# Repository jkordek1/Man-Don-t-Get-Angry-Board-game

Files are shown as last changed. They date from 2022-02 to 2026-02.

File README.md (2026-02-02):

# Man, Don't Get Angry - Board game


[]()



## About


Mensch ärgere Dich nicht (English: Man, Don't Get Angry) is a German board game developed by Josef Friedrich Schmidt in 1907/1908.
The name derives from the fact that a peg is sent back to the "out" field when another peg lands on it, similar to the later game Sorry!.

More information about the game can be found at the [wiki page](https://en.wikipedia.org/wiki/Mensch_%C3%A4rgere_Dich_nicht).

## Project idea
Idea of the project is to create an electronic version of the game to help promoting STEM education (and to have some fun of course).

## Project status
- [x] Breadboard prototype
- [x] Schematic
- [x] PCBs
- [x] Enclosure design
- [x] 3D CAD assembly and renders
- [x] Assembly
- [ ] Programming

## Issues
- no active issues

## Main features
- Based on popular ATmega328p microcontroller used on Arduino boards
- WS2812B-V5 addressable LEDs with no external components needed
- WS2812-mini addressable LED used as battery level indicator
- Touchpads connected via PCF8575 I/O Expander used as controls
- Piezo buzzer for audio queues
- 3000mAh rechargable Li-Po battery
- USB-C connector for charging and programming the microcontroller

## 3D renders
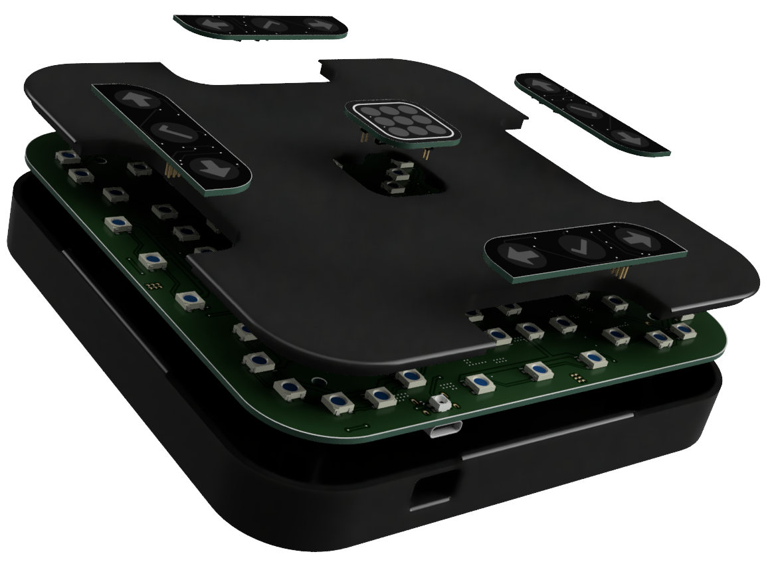
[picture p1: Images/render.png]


## Images
<p align="center">
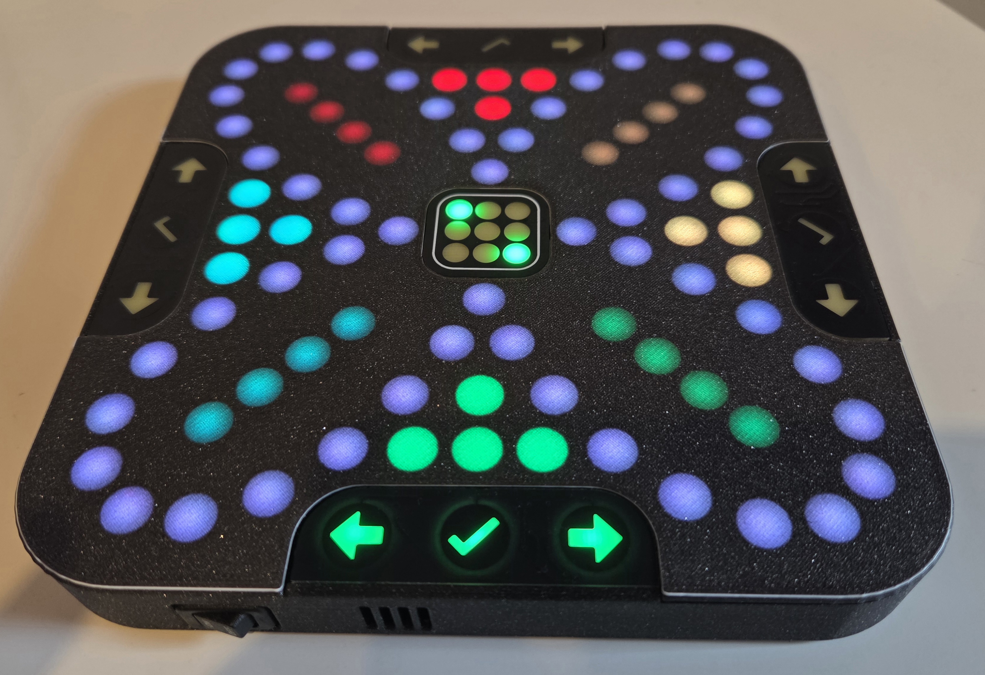
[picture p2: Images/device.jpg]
  
</p>

## PCBs
There are 3 different PCBs:

**BoardGame** - main 150x150mm PCB that contains LEDs and most of the electronic components (1 needed)

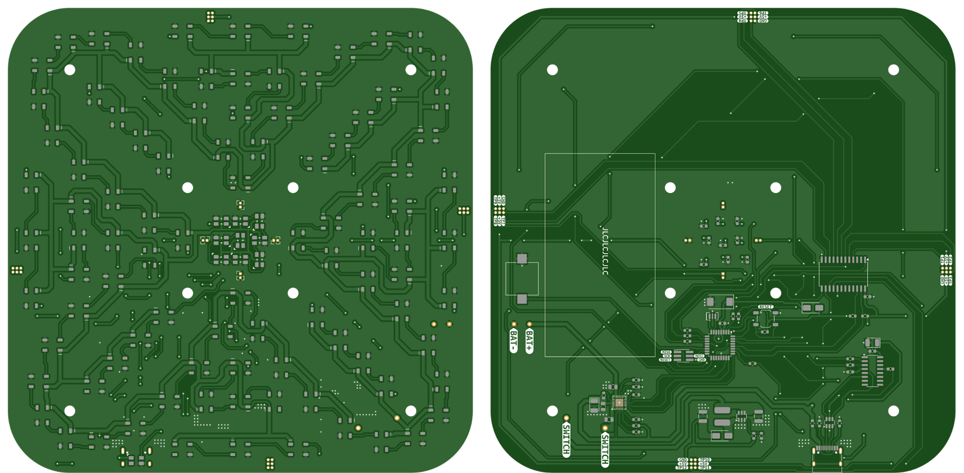
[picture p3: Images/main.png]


**Dice** - small PCB used as a touchpad (1 needed)

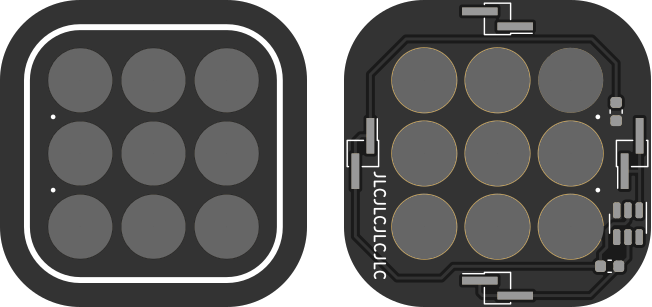
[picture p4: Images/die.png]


**Touchpad** - PCB with 3 touchpads used as controls for the game (4 needed)

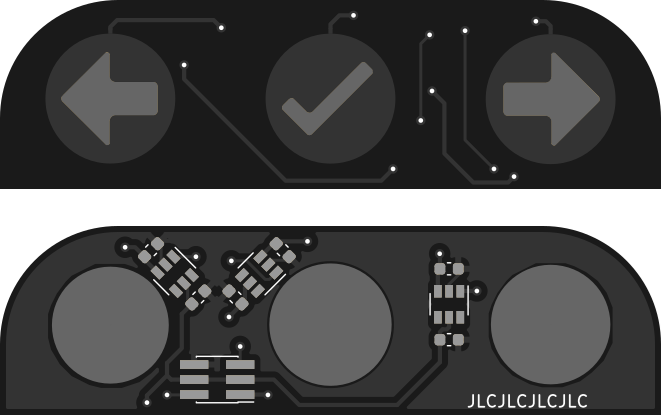
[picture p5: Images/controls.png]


## Enclosure
There are few 3D models files needed for enclosure:
1. Case - main part of the enclosure
2. FieldBoard - Upper part of the enclosure printed with black and white filaments

## Project folder structure
    .
    ├── ...
    ├── Images                  # Images of the project
    ├── Solidworks assembly     # Enclosure and PCB 3D model files
    ├── KiCad files             # Main folder
    │   ├── 3D models           # 3d models of components
    │   ├── BoardGame           # KiCAD project for main PCB
    │   ├── Dice                # KiCAD project for dice
    │   └── Touchpad            # KiCAD project for touchpad controls
    └── ...

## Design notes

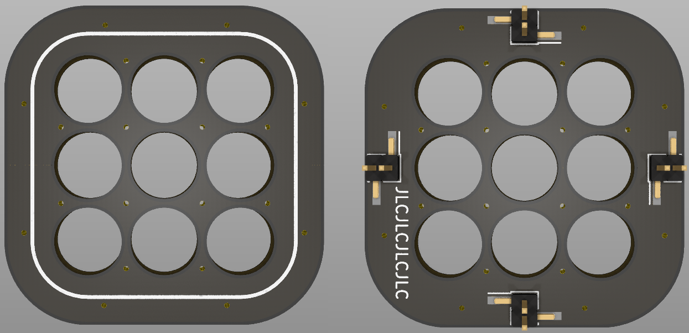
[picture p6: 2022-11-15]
Images/Dice-front and back.png

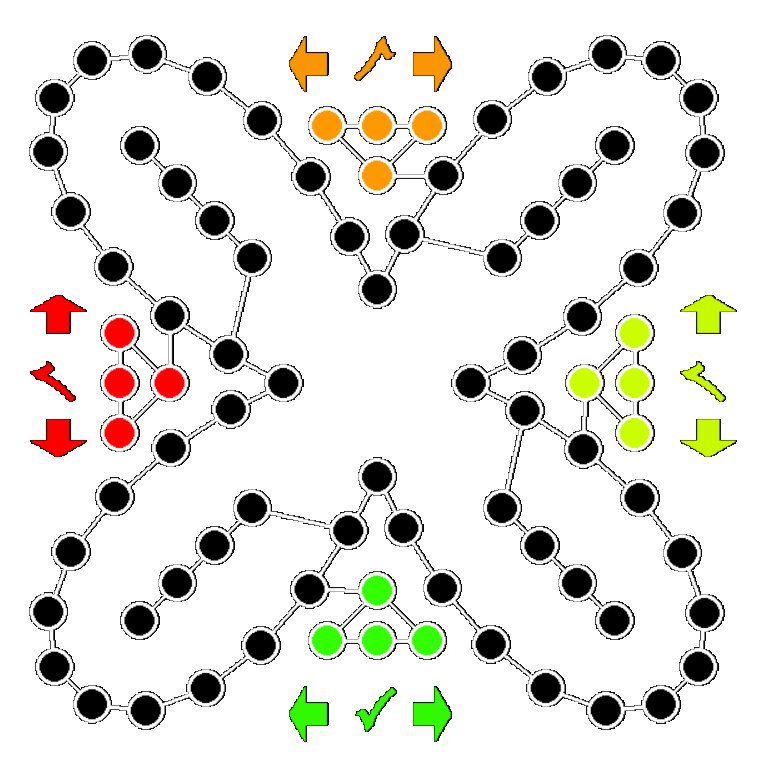
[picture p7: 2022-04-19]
Images/Positions_v3.png

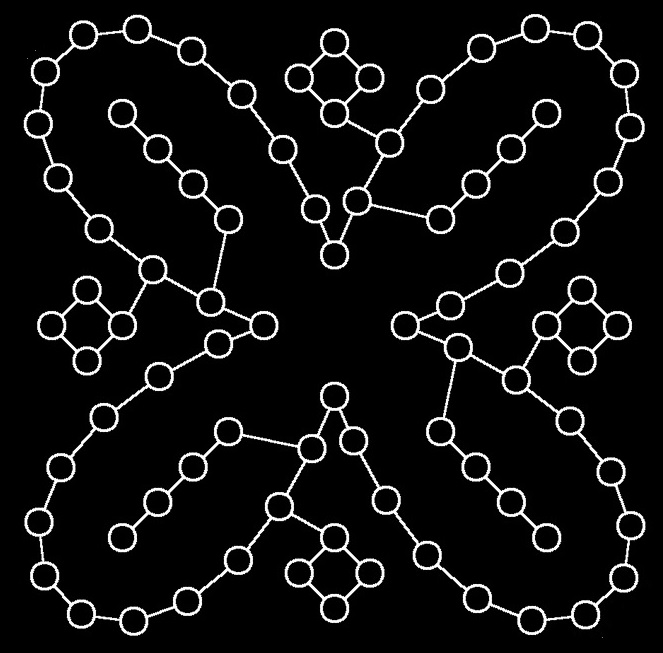
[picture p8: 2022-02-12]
Images/Positions_rotated.jpg

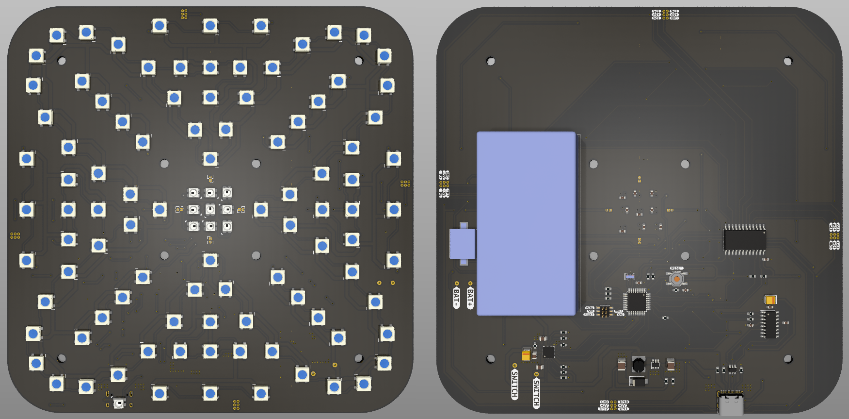
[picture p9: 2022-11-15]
Images/BoardGame-front and back.png

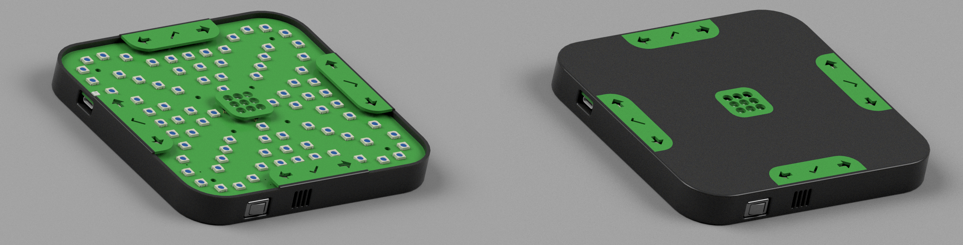
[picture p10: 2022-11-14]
Images/BoardGameV1.png

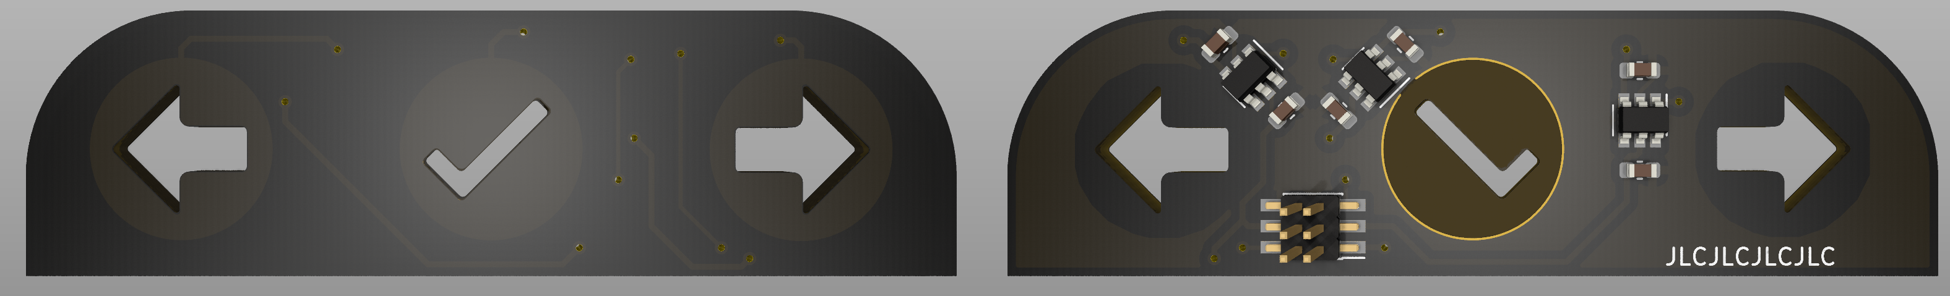
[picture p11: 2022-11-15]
Images/Touchpad-front and back.png

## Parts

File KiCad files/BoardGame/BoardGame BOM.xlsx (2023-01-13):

Component | Part | Value | Footprint | Quantity Per PCB | Datasheet
1 | C_Small | 100n | C_0603_1608Metric | 30 | ~
2 | C_Small | 1u | C_0603_1608Metric | 1 | ~
3 | C_Polarized_Small | 10u | CP_EIA-3528-21_Kemet-B | 1 | ~
4 | C_Small | 10u | C_0805_2012Metric | 3 | ~
5 | C_Polarized_Small | 1500uF | CP_EIA-7343-31_Kemet-D | 1 | ~
6 | C_Small | 22u / 16V | C_1210_3225Metric | 2 | ~
7 | C_Polarized_Small | 4u7/25V | CP_EIA-3528-21_Kemet-B | 1 | ~
8 | D_Schottky_Small | SS12 | D_SMA | 2 | ~
9 | WS2812B-V5 | WS2812B-V5 | WS2812B-V5 | 96 | https://cdn-shop.adafruit.com/datasheets/WS2812B.pdf
10 | WS2812B-mini | WS2812B-mini | WS2812B-mini | 10
11 | FerriteBead | 100 @ 100MHz | R_0603_1608Metric | 1 | ~
12 | Conn_02x03_Odd_Even | USBasp | PinHeader_2x03_P1.27mm_Vertical_SMD | 1 | ~
13 | L_Small | 4R7 | Inductor_4mm(5x5mm pads) | 1 | ~
14 | Speaker | Buzzer | KLJ-1102 | 1 | ~
15 | R_Small | 470R | R_0603_1608Metric | 6 | ~
16 | R_Small | 1k | R_0603_1608Metric | 2 | ~
17 | R_Small | 2k | R_0603_1608Metric | 1 | ~
18 | R_Small | 4k7 | R_0603_1608Metric | 2 | ~
19 | R_Small | 5k1 | R_0603_1608Metric | 2 | ~
20 | R_Small | 10k | R_0603_1608Metric | 6 | ~
21 | R_Small | 13k3 | R_0603_1608Metric | 1 | ~
22 | R_Small | 100k | R_0603_1608Metric | 2 | ~
23 | SW_Push | SW_Push | SW_SPST_TL3342 | 1 | ~
24 | ATmega328P-A | ATmega328P-A | TQFP-32_7x7mm_P0.8mm | 1 | http://ww1.microchip.com/downloads/en/DeviceDoc/ATmega328_P%20AVR%20MCU%20with%20picoPower%20Technology%20Data%20Sheet%2040001984A.pdf
25 | CH340C | CH340C | SOIC-16_3.9x9.9mm_P1.27mm | 1 | https://datasheet.lcsc.com/szlcsc/Jiangsu-Qin-Heng-CH340C_C84681.pdf
26 | MCP73871-2CC | MCP73871-2CC | QFN-20-1EP_4x4mm_P0.5mm_EP2.5x2.5mm | 1 | http://www.mouser.com/ds/2/268/22090a-52174.pdf
27 | MT3608 | MT3608 | SOT-23-6 | 1 | https://www.olimex.com/Products/Breadboarding/BB-PWR-3608/resources/MT3608.pdf
28 | PCF8575 | PCF8575 | SOIC-24W_7.5x15.4mm_P1.27mm | 1
29 | USBLC6-2SC6 | USBLC6-2SC6 | SOT-23-6 | 1 | https://www.st.com/resource/en/datasheet/usblc6-2.pdf
30 | Resonator_Small | 16MHz | CSTCE16M0V53-R0 | 1 | ~
31 | C_Small | 50 pF | C_0603_1608Metric | 15
32 | Conn_02x03_Counter_Clockwise | Conn_02x03_Counter_Clockwise | PinHeader_2x03_P1.27mm_Vertical_SMD | 4
33 | TTP223-BA6 | TTP223-BA6 | SOT-23-6 | 15
34 | Conn_01x02_Male | Conn_01x02_Male | PinHeader_1x02_P1.27mm_Vertical_SMD_Pin1Left | 4
35 | Conn_01x02_Male | Conn_01x02_Male | PinHeader_1x02_P1.27mm_Vertical_SMD_Pin1Left | 4

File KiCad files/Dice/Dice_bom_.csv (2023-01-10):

Component | Description | Part | References | Value | Footprint | Quantity Per PCB | Datasheet
1 | Unpolarized capacitor, small symbol | C_Small | C1 | 100n | C_0603_1608Metric | 1 | ~
2 | Unpolarized capacitor, small symbol | C_Small | C2 | 0-50 pF | C_0603_1608Metric | 1 | ~
3 | Generic connector, single row, 01x02, script generated (kicad-library-utils/schlib/autogen/connector/) | Conn_01x02_Male | J1 J2 J3 J4 | Conn_01x02_Male | PinHeader_1x02_P1.27mm_Vertical_SMD_Pin1Left | 4 | ~
4 |  | TTP223-BA6 | U1 | TTP223-BA6 | SOT-23-6 | 1
Component Groups: | 4
Component Count: | 7
Fitted Components: | 7
Number of PCBs: | 1
Total components: | 7
Schematic Version:
Schematic Date:
PCB Variant: | default
BoM Date: | 10.1.2023. 13:12:25
Schematic Source: | Dice.kicad_sch
KiCad Version: | Eeschema (6.0.10)

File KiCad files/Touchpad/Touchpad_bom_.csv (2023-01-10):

Component | Description | Part | References | Value | Footprint | Quantity Per PCB | Datasheet
1 | Unpolarized capacitor, small symbol | C_Small | C2 C4 C6 | 100n | C_0603_1608Metric | 3 | ~
2 | Unpolarized capacitor, small symbol | C_Small | C1 C3 C5 | 0-50 pF | C_0603_1608Metric | 3 | ~
3 | Generic connector, double row, 02x03, counter clockwise pin numbering scheme (similar to DIP packge numbering), script generated (kicad-library-utils/schlib/autogen/connector/) | Conn_02x03_Counter_Clockwise | J1 | Conn_02x03_Counter_Clockwise | PinHeader_2x03_P1.27mm_Vertical_SMD | 1 | ~
4 |  | TTP223-BA6 | U1 U2 U3 | TTP223-BA6 | SOT-23-6 | 3
Component Groups: | 4
Component Count: | 10
Fitted Components: | 10
Number of PCBs: | 1
Total components: | 10
Schematic Version:
Schematic Date:
PCB Variant: | default
BoM Date: | 10.1.2023. 13:06:24
Schematic Source: | Touchpad.kicad_sch
KiCad Version: | Eeschema (6.0.10)

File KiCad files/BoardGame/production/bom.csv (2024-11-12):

Designator | Footprint | Quantity | Value | LCSC Part #
BT301 | battery_103565_3000mah | 1 | Battery_Cell | -
C1001, C1002, C1003, C1004, C1005, C1006, C1007, C1008, C1009, C201, C202, C204, C401, C501 | 0603 | 14 | 100n | C113803
C203 | CP_EIA-3528-21_Kemet-B | 1 | 10u | C2798040
C301 | CP_EIA-3528-21_Kemet-B | 1 | 4u7/25V | C2798040
C302, C303, C304 | 0805 | 3 | 10u | C237493
C502 | CP_EIA-7343-31_Kemet-D | 1 | 1500uF
C601, C602 | 1210 | 2 | 22u / 16V | C337451
D1001, D1002, D1003, D1004, D1005, D1006, D1007, D1008, D1009, D1010, D1011, D1012, D1013, D1014, D1015, D1016, D1017, D1018, D1019, D1020, D1021, D1022, D1023, D1024, D1025, D1026, D1027, D1028, D1029, D1030, D1031, D1032, D1033, D1034, D1035, D1036, D1037, D1038, D1039, D1040, D1041, D1042, D1043, D1044, D1045, D1046, D1047, D1048, D1049, D1050, D1051, D1052, D1053, D1054, D1055, D1056, D1057, D1058, D1059, D1060, D1061, D1062, D1063, D1064, D1065, D1066, D1067, D1068, D1069, D1070, D1071, D1072, D1073, D1074, D1075, D1076, D1077, D1078, D1079, D1080, D1081, D1082, D1083, D1084, D1085, D1086, D1087, D1088, D1089, D1090, D1091, D1092, D1093, D1094, D1095, D1096 | LED_WS2812B_edited | 96 | WS2812B | -
D1097, D1098, D1099, D1100, D1101, D1102, D1103, D1104, D1105 | WS2812-mini | 9 | WS2812B | C527089
D1106 | WS2812-mini | 1 | WS2812B | -
D501, D601 | D_SMA | 2 | SS12 | C2985002
FB201 | 0603 | 1 | 100 @ 100MHz | C107332
H1001, H1002, H1003, H1004, H1005, H1006, H1007, H1008 | MountingHole_3.2mm_M3 | 8 | MountingHole
J201 | USB_C_Receptacle_HRO_TYPE-C-31-M-12 | 1 | USB_C_Receptacle_USB2.0 | -
J301, J302 | PinHeader_1x01 | 2 | Conn_01x01 | -
J401, J402, J403, J404 | 2x03_P1.27mm_conn | 4 | Conn_02x03_Odd_Even | -
J405, J406, J407, J408 | PinHeader_1x02_P1.27mm_Vertical | 4 | Conn_01x02_Female
J501 | PinHeader_2x03_P1.27mm_Vertical_SMD | 1 | USBasp | -
L601 | Inductor_4mm(5x5mm pads) | 1 | 4R7
LS501 | KLJ-1102 | 1 | Buzzer
R1001, R1002, R1003, R1004, R1005, R1006 | 0603 | 6 | 470R
R201, R204 | 0603 | 2 | 1k
R202, R203 | 0603 | 2 | 5k1 | C3017721
R301, R303, R307, R308, R310, R501 | 0603 | 6 | 10k
R302 | 0603 | 1 | 2k | C25590
R305, R601 | 0603 | 2 | 100k
R401, R402 | 0603 | 2 | 4k7 | C114662
R602 | 0603 | 1 | 13k3 | C185373
SW501 | SW_SPST_TL3342 | 1 | SW_Push | C2886894
U201 | SOT-23-6 | 1 | USBLC6-2SC6 | C3029034
U202 | SOIC-16_3.9x9.9mm_P1.27mm | 1 | CH340C
U301 | QFN-20-1EP_4x4mm_P0.5mm_EP2.5x2.5mm | 1 | MCP73871-2CC
U401 | SOIC-24W_7.5x15.4mm_P1.27mm | 1 | PCF8575
U501 | TQFP-32_7x7mm_P0.8mm | 1 | ATmega328P-A
U601 | SOT-23-6 | 1 | MT3608 | C2932326
Y501 | CSTCE16M0V53-R0 | 1 | 16MHz | C32180

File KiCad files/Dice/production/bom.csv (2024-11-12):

Designator | Footprint | Quantity | Value | LCSC Part #
C1 | 0603 | 1 | 100n
C2 | 0603 | 1 | 0-50 pF
J1, J2, J3, J4 | PinHeader_1x02_P1.27mm_Vertical_SMD_Pin1Left | 4 | Conn_01x02_Male
U1 | SOT-23-6 | 1 | TTP223-BA6

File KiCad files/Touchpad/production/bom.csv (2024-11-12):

Designator | Footprint | Quantity | Value | LCSC Part #
C1, C3, C5 | 0603 | 3 | 0-50 pF
C2, C4, C6 | 0603 | 3 | 100n
J1 | PinHeader_2x03_P1.27mm_Vertical_SMD | 1 | Conn_02x03_Counter_Clockwise
TP1 | TP_11mm_kvacica | 1 | TestPoint
TP2 | TP_11mm_strelicaLijevo | 1 | TestPoint
TP3 | TP_11mm_strelicaDesno | 1 | TestPoint
U1, U2, U3 | SOT-23-6 | 3 | TTP223-BA6

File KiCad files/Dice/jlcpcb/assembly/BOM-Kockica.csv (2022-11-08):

Comment | Designator | Footprint | LCSC
Conn_01x02_Male | J1 | PinHeader_1x02_P1.27mm_Vertical_SMD_Pin1Left
Conn_01x02_Male | J4 | PinHeader_1x02_P1.27mm_Vertical_SMD_Pin1Left
Conn_01x02_Male | J3 | PinHeader_1x02_P1.27mm_Vertical_SMD_Pin1Left
Conn_01x02_Male | J2 | PinHeader_1x02_P1.27mm_Vertical_SMD_Pin1Left

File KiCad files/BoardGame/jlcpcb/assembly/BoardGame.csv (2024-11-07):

Id | Package | Quantity | Designation
1 | D_SMA | 2 | SS12
2 | LED_WS2812B_edited | 96 | WS2812B
3 | WS2812-mini | 10 | WS2812B
4 | MountingHole_3.2mm_M3 | 8 | MountingHole
5 | 2x03_P1.27mm_conn | 4 | Conn_02x03_Odd_Even
6 | PinHeader_1x01 | 2 | Conn_01x01
7 | PinHeader_1x02_P1.27mm_Vertical | 4 | Conn_01x02_Female
8 | C_0603_1608Metric | 14 | 100n
9 | R_0603_1608Metric | 6 | 10k
10 | C_0603_1608Metric | 1 | 1u
11 | R_0603_1608Metric | 2 | 1k
12 | R_0603_1608Metric | 2 | 4k7
13 | R_0603_1608Metric | 6 | 470R
14 | R_0603_1608Metric | 2 | 5k1
15 | KLJ-1102 | 1 | Buzzer
16 | TQFP-32_7x7mm_P0.8mm | 1 | ATmega328P-A
17 | R_0603_1608Metric | 1 | 13k3
18 | C_1210_3225Metric | 2 | 22u / 16V
19 | CP_EIA-3528-21_Kemet-B | 1 | 10u
20 | Inductor_4mm(5x5mm pads) | 1 | 4R7
21 | C_0805_2012Metric | 3 | 10u
22 | USB_C_Receptacle_HRO_TYPE-C-31-M-12 | 1 | USB_C_Receptacle_USB2.0
23 | R_0603_1608Metric | 1 | 100 @ 100MHz
24 | SOT-23-6 | 1 | MT3608
25 | CP_EIA-3528-21_Kemet-B | 1 | 4u7/25V
26 | SOIC-16_3.9x9.9mm_P1.27mm | 1 | CH340C
27 | SOT-23-6 | 1 | USBLC6-2SC6
28 | SW_SPST_TL3342 | 1 | SW_Push
29 | R_0603_1608Metric | 2 | 100k
30 | CP_EIA-7343-31_Kemet-D | 1 | 1500uF
31 | battery_103565_3000mah | 1 | Battery_Cell
32 | R_0603_1608Metric | 1 | 2k
33 | SOIC-24W_7.5x15.4mm_P1.27mm | 1 | PCF8575
34 | CSTCE16M0V53-R0 | 1 | 16MHz
35 | QFN-20-1EP_4x4mm_P0.5mm_EP2.5x2.5mm | 1 | MCP73871-2CC
36 | PinHeader_2x03_P1.27mm_Vertical_SMD | 1 | USBasp

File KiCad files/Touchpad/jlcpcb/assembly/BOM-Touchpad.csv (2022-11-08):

Comment | Designator | Footprint | LCSC
TestPoint | TP3 | TP_11mm_strelicaDesno
TestPoint | TP1 | TP_11mm_kvacica
TestPoint | TP2 | TP_11mm_strelicaLijevo
0-50 pF | C3 | C_0603_1608Metric
100n | C2 | C_0603_1608Metric
TTP223-BA6 | U3 | SOT-23-6
100n | C4 | C_0603_1608Metric
100n | C6 | C_0603_1608Metric
TTP223-BA6 | U2 | SOT-23-6
0-50 pF | C1 | C_0603_1608Metric
TTP223-BA6 | U1 | SOT-23-6
Conn_02x03_Counter_Clockwise | J1 | PinHeader_2x03_P1.27mm_Vertical_SMD
0-50 pF | C5 | C_0603_1608Metric

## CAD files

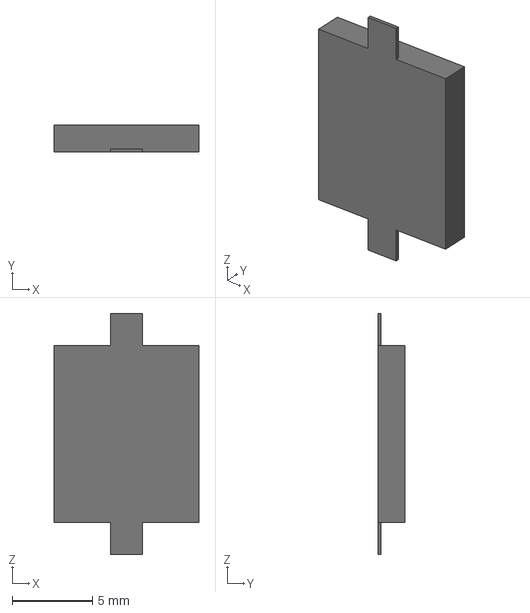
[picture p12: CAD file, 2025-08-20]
KiCad files/3D models/KLJ-1102.STEP
9.00 x 1.70 x 15.0 mm

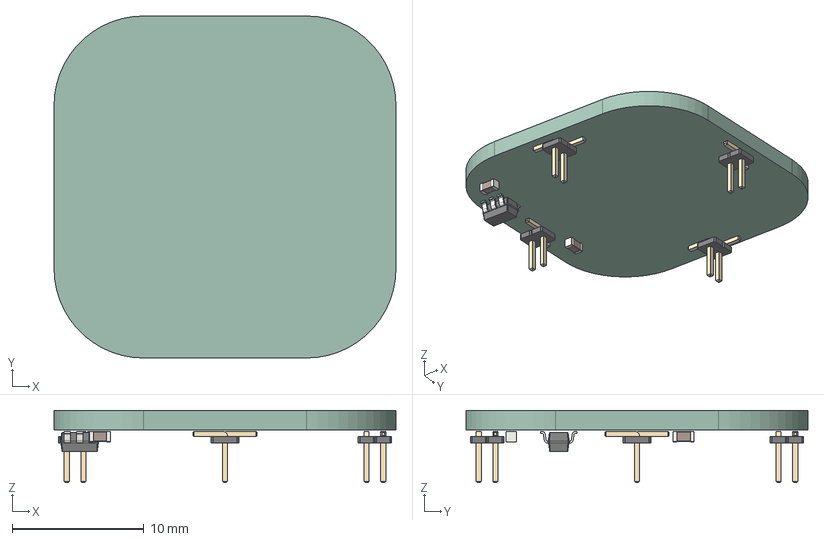
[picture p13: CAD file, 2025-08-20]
KiCad files/Dice/Kockica.step
26.0 x 26.0 x 5.50 mm
PinHeader_1x02_P1.27mm_Vertical_SMD_Pin1Left x 4
SOT-23-6
C_0603_1608Metric x 2
Dice_PCB

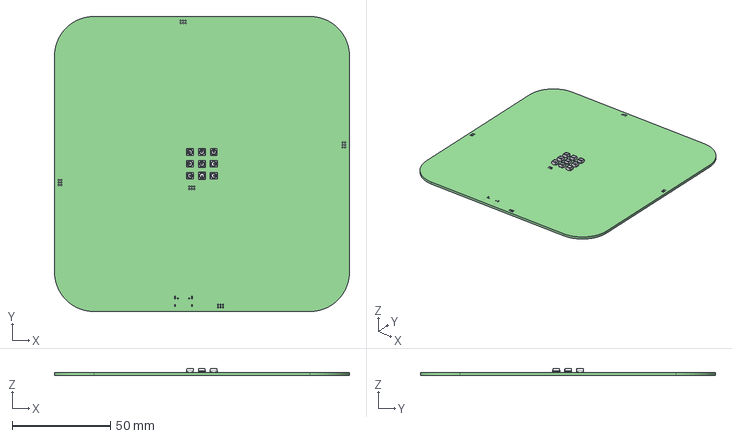
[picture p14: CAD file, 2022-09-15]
KiCad files/Main Project/CNLJS.step
150.0 x 150.0 x 3.55 mm
CNLJS PCB

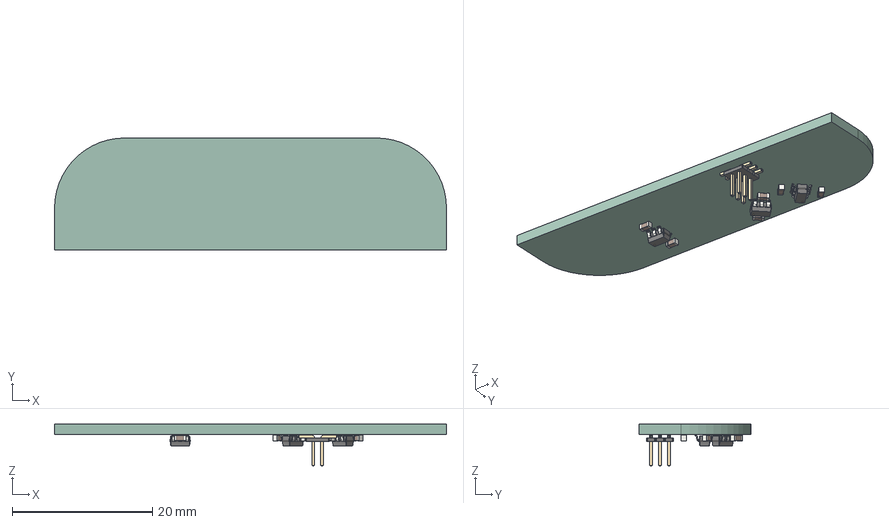
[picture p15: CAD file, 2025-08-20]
KiCad files/Touchpad/Touchpad.step
56.0 x 16.0 x 6.00 mm
C_0603_1608Metric x 6
SOT-23-6 x 3
PinHeader_2x03_P1.27mm_Vertical_SMD
Touchpad_PCB

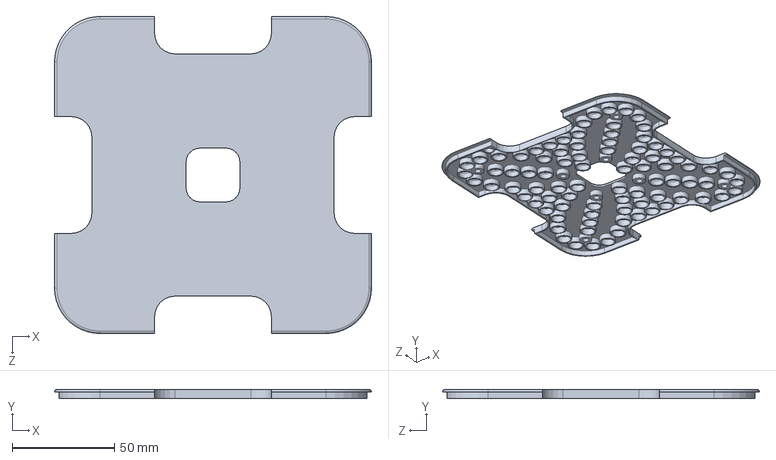
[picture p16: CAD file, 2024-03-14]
Solidworks assembly/GornjaStrana_v6.SLDPRT
154.8 x 4.40 x 154.8 mm

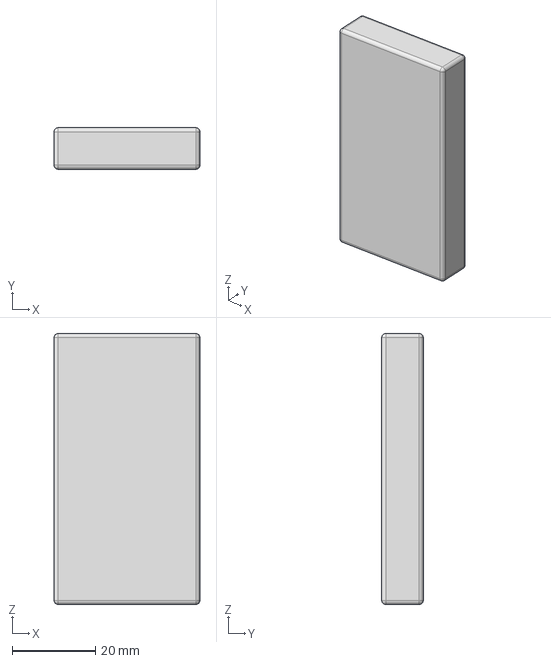
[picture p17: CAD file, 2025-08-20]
KiCad files/3D models/battery_103565.STEP
35.0 x 10.0 x 65.0 mm

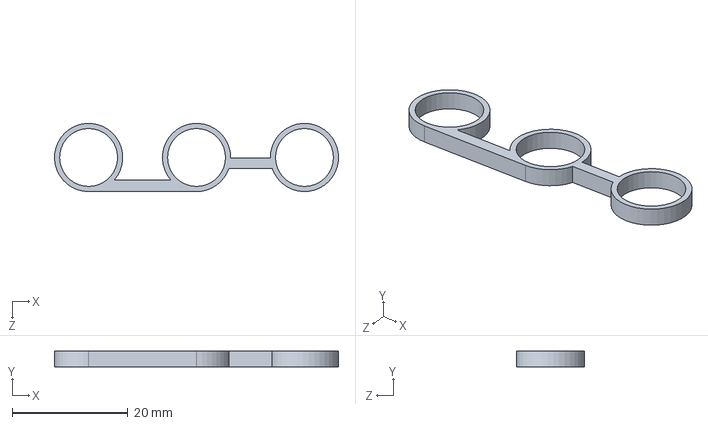
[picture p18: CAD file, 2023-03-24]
Solidworks assembly/odstojnik.SLDPRT
49.1 x 2.70 x 11.8 mm

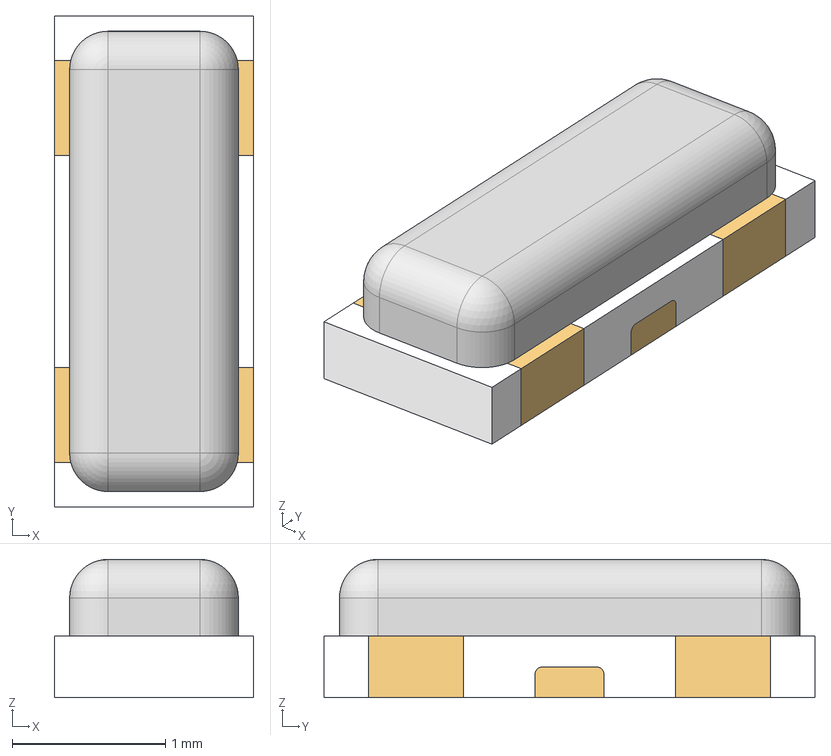
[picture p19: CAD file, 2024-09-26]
KiCad files/3D models/CSTCE.stp
1.30 x 3.20 x 0.9 mm
BASE
PIN2
PIN1 AND PIN3 x 2
HAT

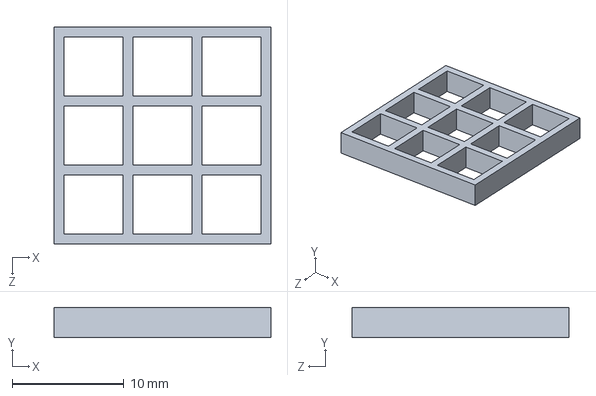
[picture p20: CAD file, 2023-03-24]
Solidworks assembly/kockica pregrada.SLDPRT
19.5 x 2.70 x 19.5 mm

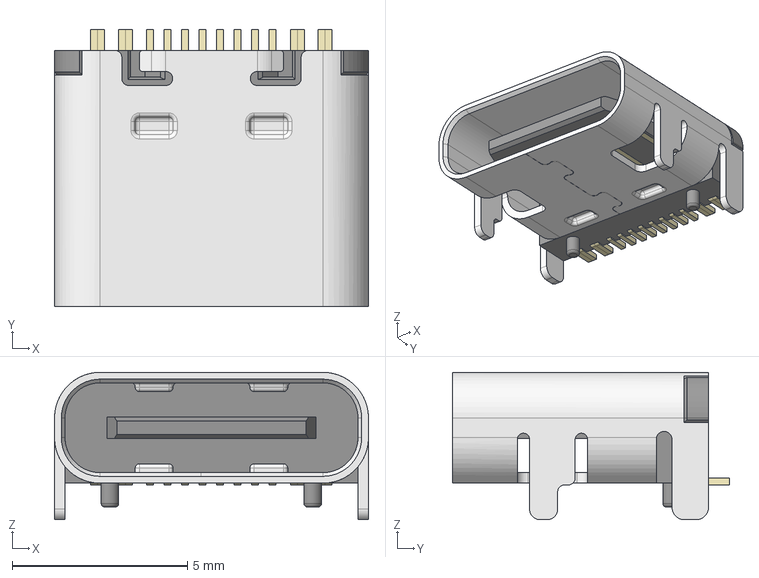
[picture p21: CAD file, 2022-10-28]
KiCad files/3D models/HRO_TYPE-C-31-M-12.step
8.95 x 7.90 x 4.20 mm

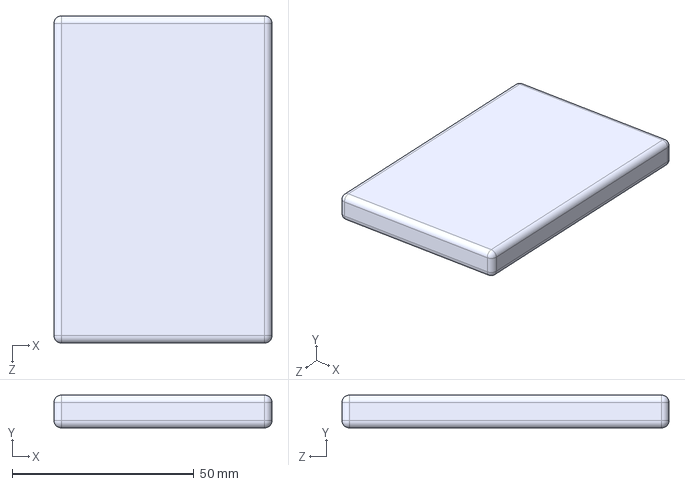
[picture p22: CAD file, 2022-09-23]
KiCad files/3D models/battery_906090_6000mah.STEP
60.0 x 9.00 x 90.0 mm

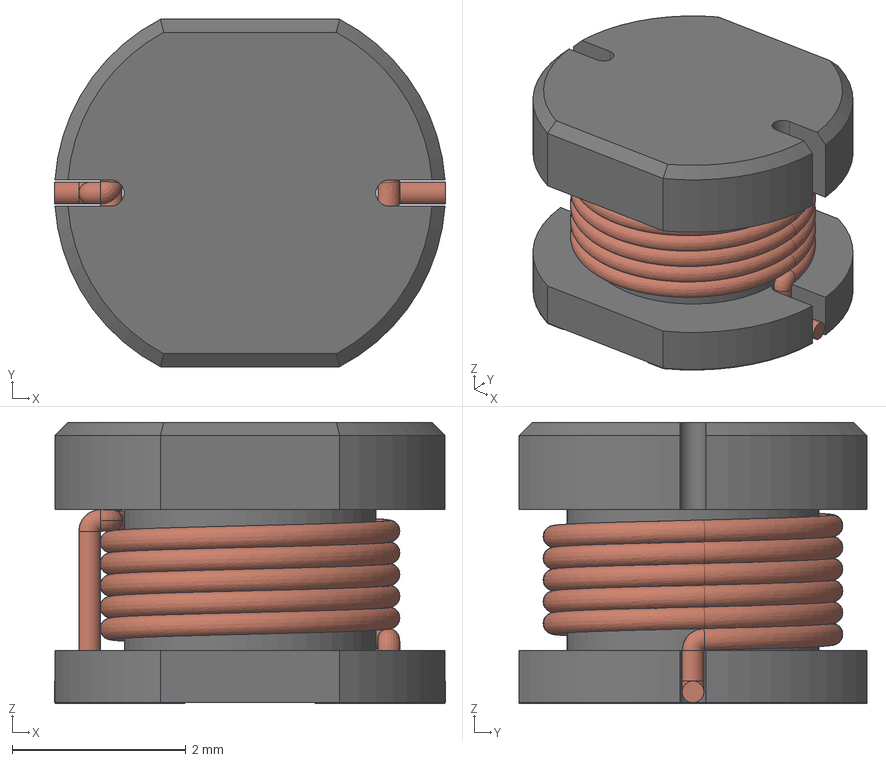
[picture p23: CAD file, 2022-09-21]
KiCad files/3D models/SMD_Inductor_CD43.step
4.50 x 4.00 x 3.23 mm

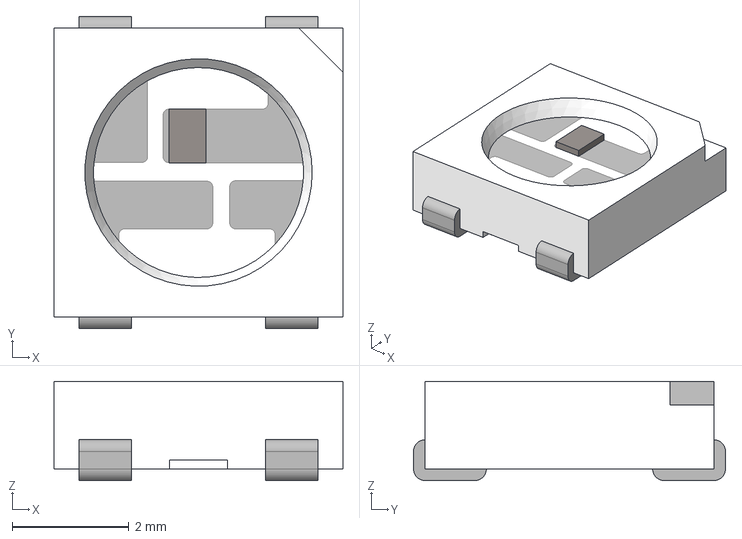
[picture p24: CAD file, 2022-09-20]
KiCad files/3D models/WS2812_RGB_LED_updated.stp
4.95 x 5.35 x 1.70 mm

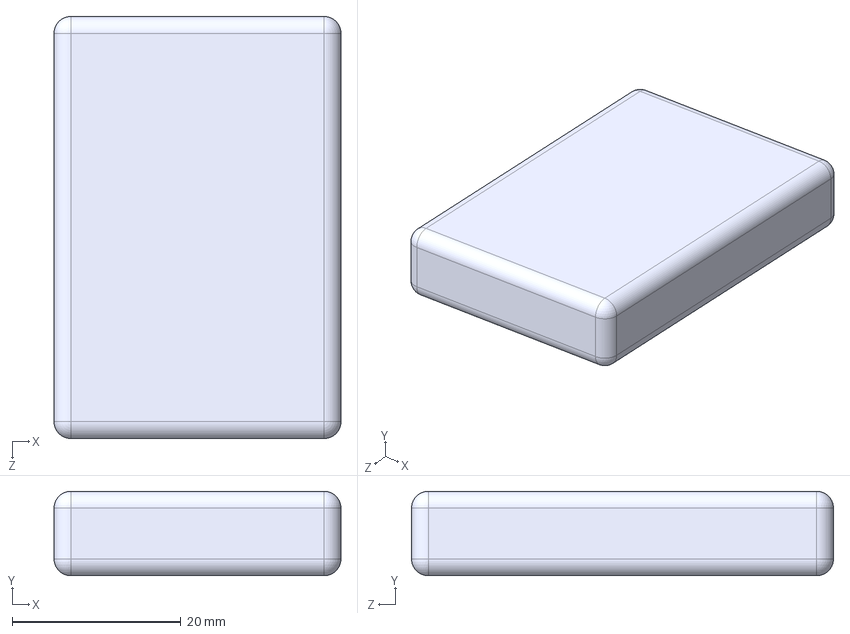
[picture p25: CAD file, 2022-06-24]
KiCad files/3D models/battery_103450.STEP
34.0 x 10.0 x 50.0 mm

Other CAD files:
KiCad files/BoardGame/SOLID-36.step.SLDPRT
KiCad files/BoardGame/SOLID-29.step.SLDPRT
KiCad files/Touchpad/SOLID.step.SLDPRT
KiCad files/Touchpad/SOLID-1.step.SLDPRT
KiCad files/3D models/WS2812-4020.STEP
KiCad files/3D models/WS2812B Mini.step
KiCad files/3D models/WS2812B.step
Solidworks assembly/COMPOUND-28.step.SLDPRT
Solidworks assembly/COMPOUND-7.step.SLDPRT
Solidworks assembly/COMPOUND.step.SLDPRT
Solidworks assembly/Case_v1.SLDPRT
Solidworks assembly/Case_v2.SLDPRT
Solidworks assembly/GornjaStrana.SLDPRT
Solidworks assembly/GornjaStrana_v2.SLDPRT
Solidworks assembly/GornjaStrana_v3.SLDPRT
Solidworks assembly/GornjaStrana_v4.SLDPRT
Solidworks assembly/GornjaStrana_v5.SLDPRT
Solidworks assembly/PRK22J5DBBNN.SLDPRT
Solidworks assembly/SOLID-0.step.SLDPRT
Solidworks assembly/SOLID-1.step.SLDPRT
Solidworks assembly/SOLID-10.step.SLDPRT
Solidworks assembly/SOLID-11.step.SLDPRT
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

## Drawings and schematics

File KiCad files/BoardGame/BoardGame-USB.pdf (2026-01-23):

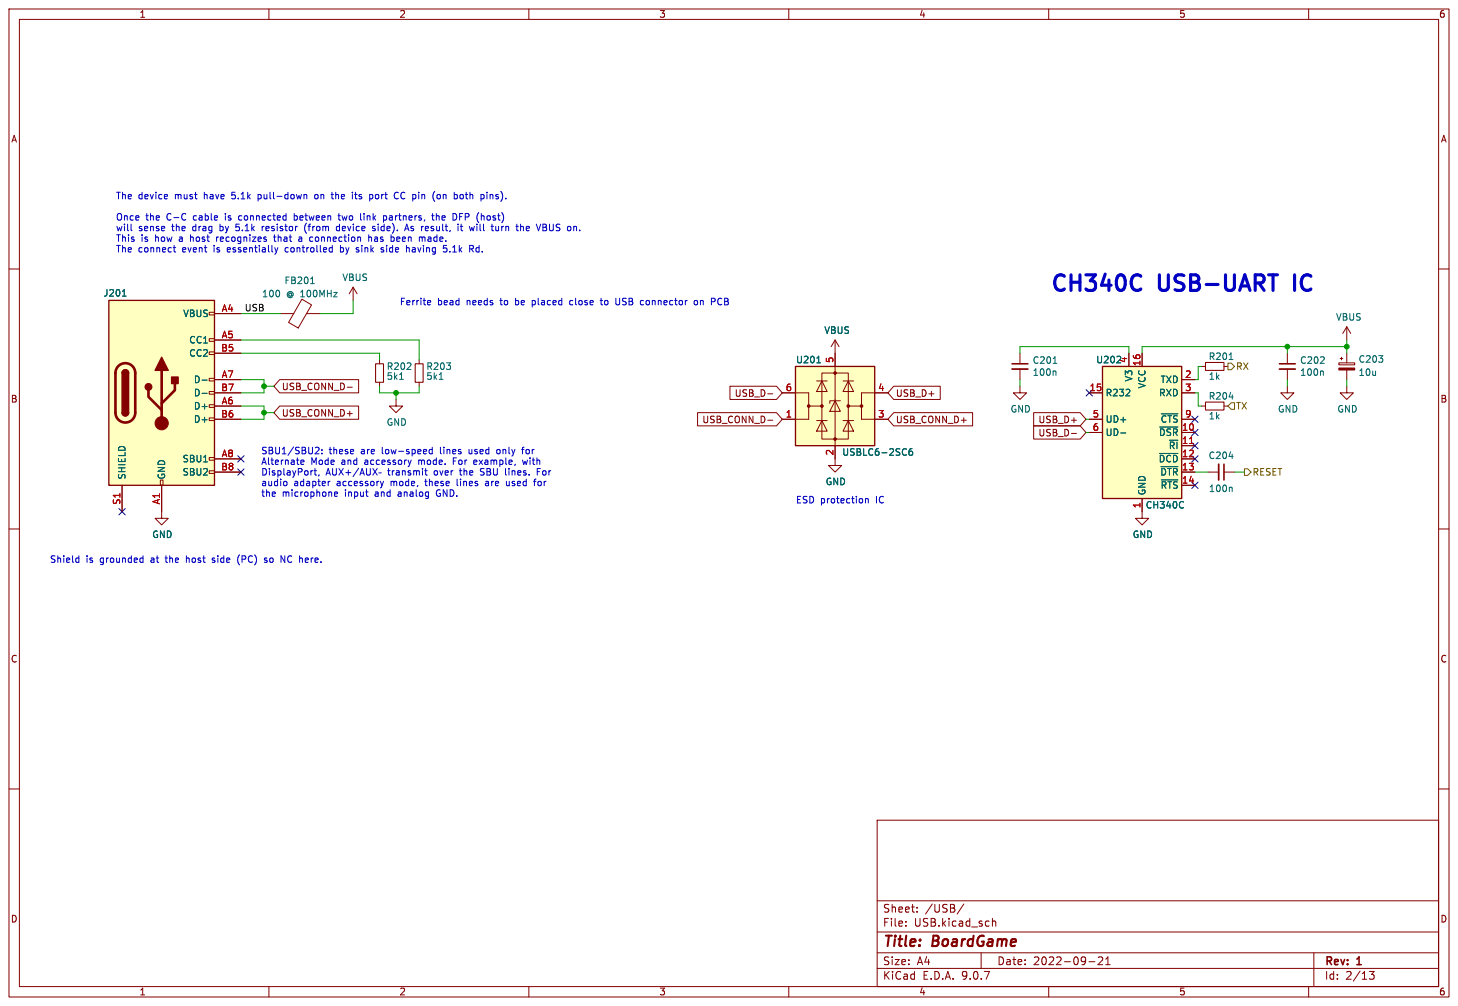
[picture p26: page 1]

1 TXD 2 RXD 3 ~{CTS}9 ~{DSR} 10 ~{RI} 11 ~{DCD} 12 ~{DTR} 13 ~{RTS} GND 14 VBUS U201 USBLC6-2SC6

1 TXD 2 RXD 3 ~{CTS}9 ~{DSR} 10 ~{RI} 11 ~{DCD} 12 ~{DTR} 13 ~{RTS} 14 U202 CH340C

Shield is grounded at the host side (PC) so NC here. GND

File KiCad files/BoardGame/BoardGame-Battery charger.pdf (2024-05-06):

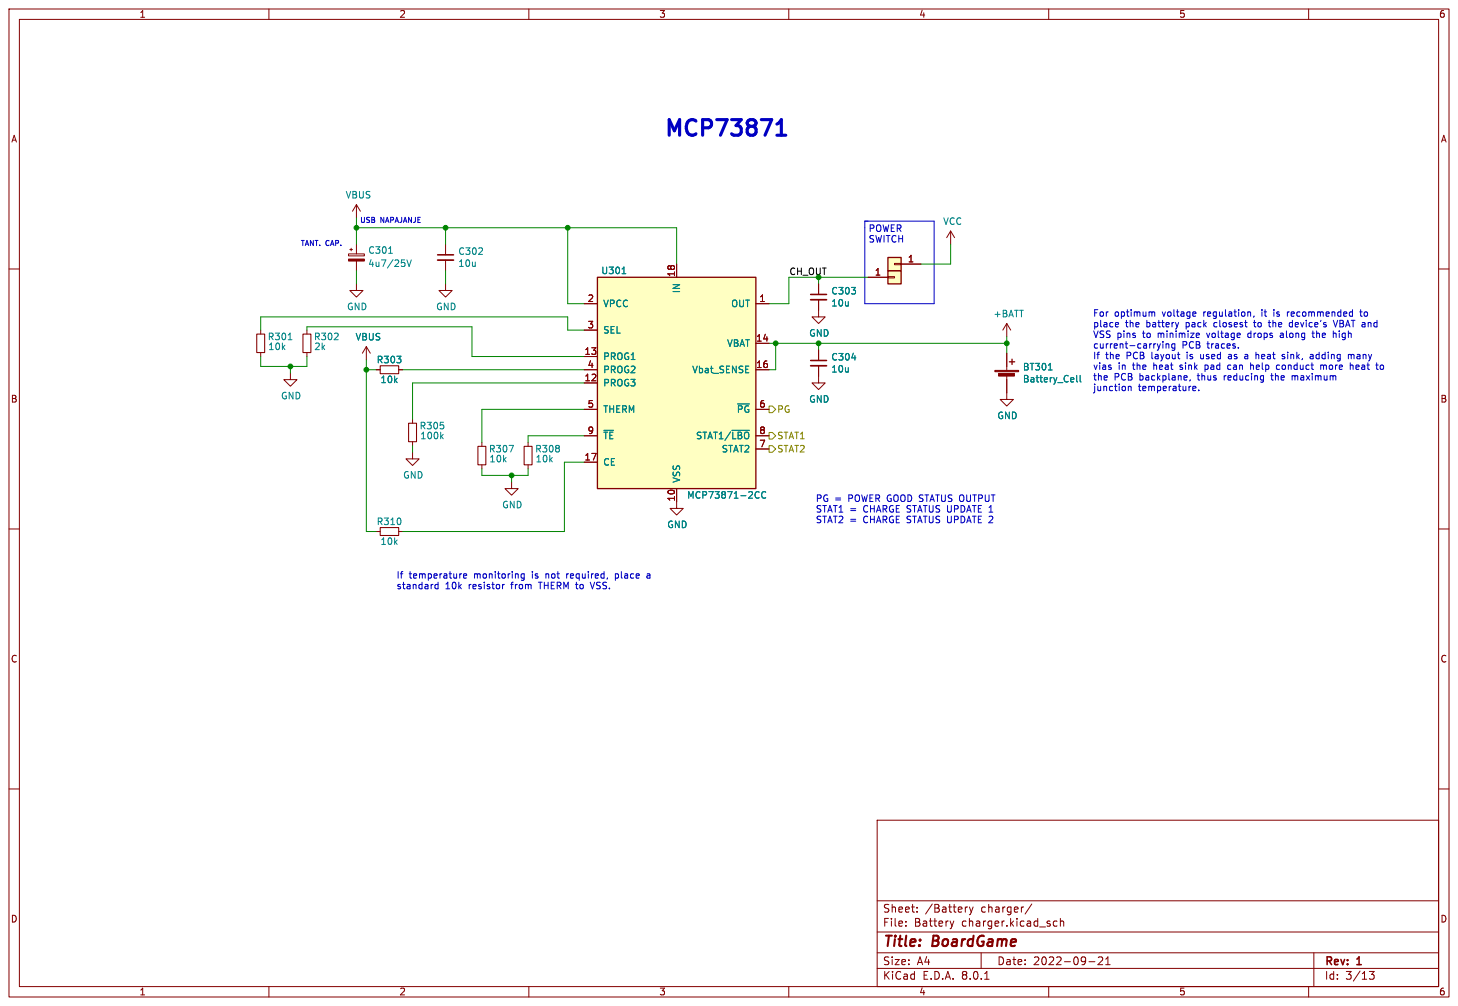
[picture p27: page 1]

If the PCB layout is used as a heat sink, adding many
vias in the heat sink pad can help conduct more heat to

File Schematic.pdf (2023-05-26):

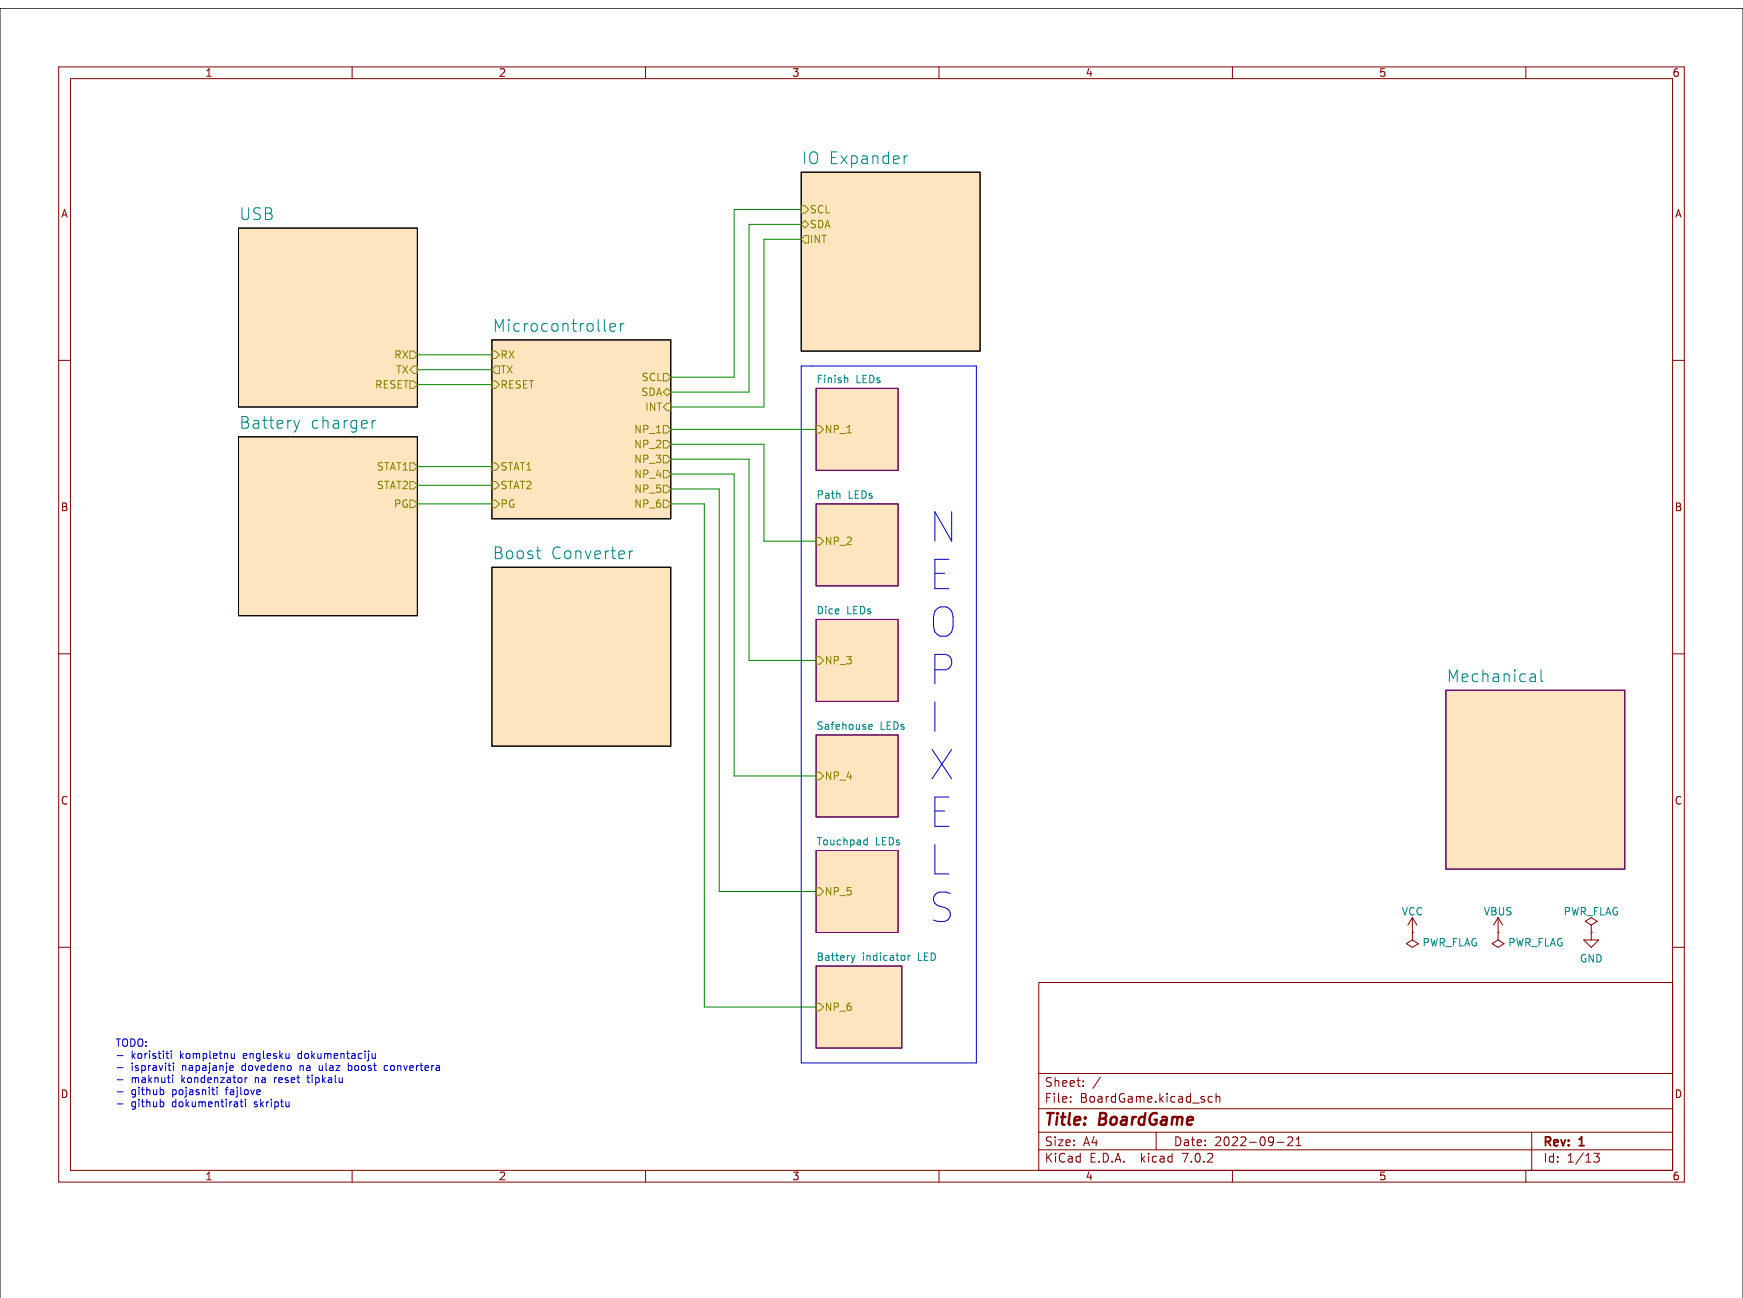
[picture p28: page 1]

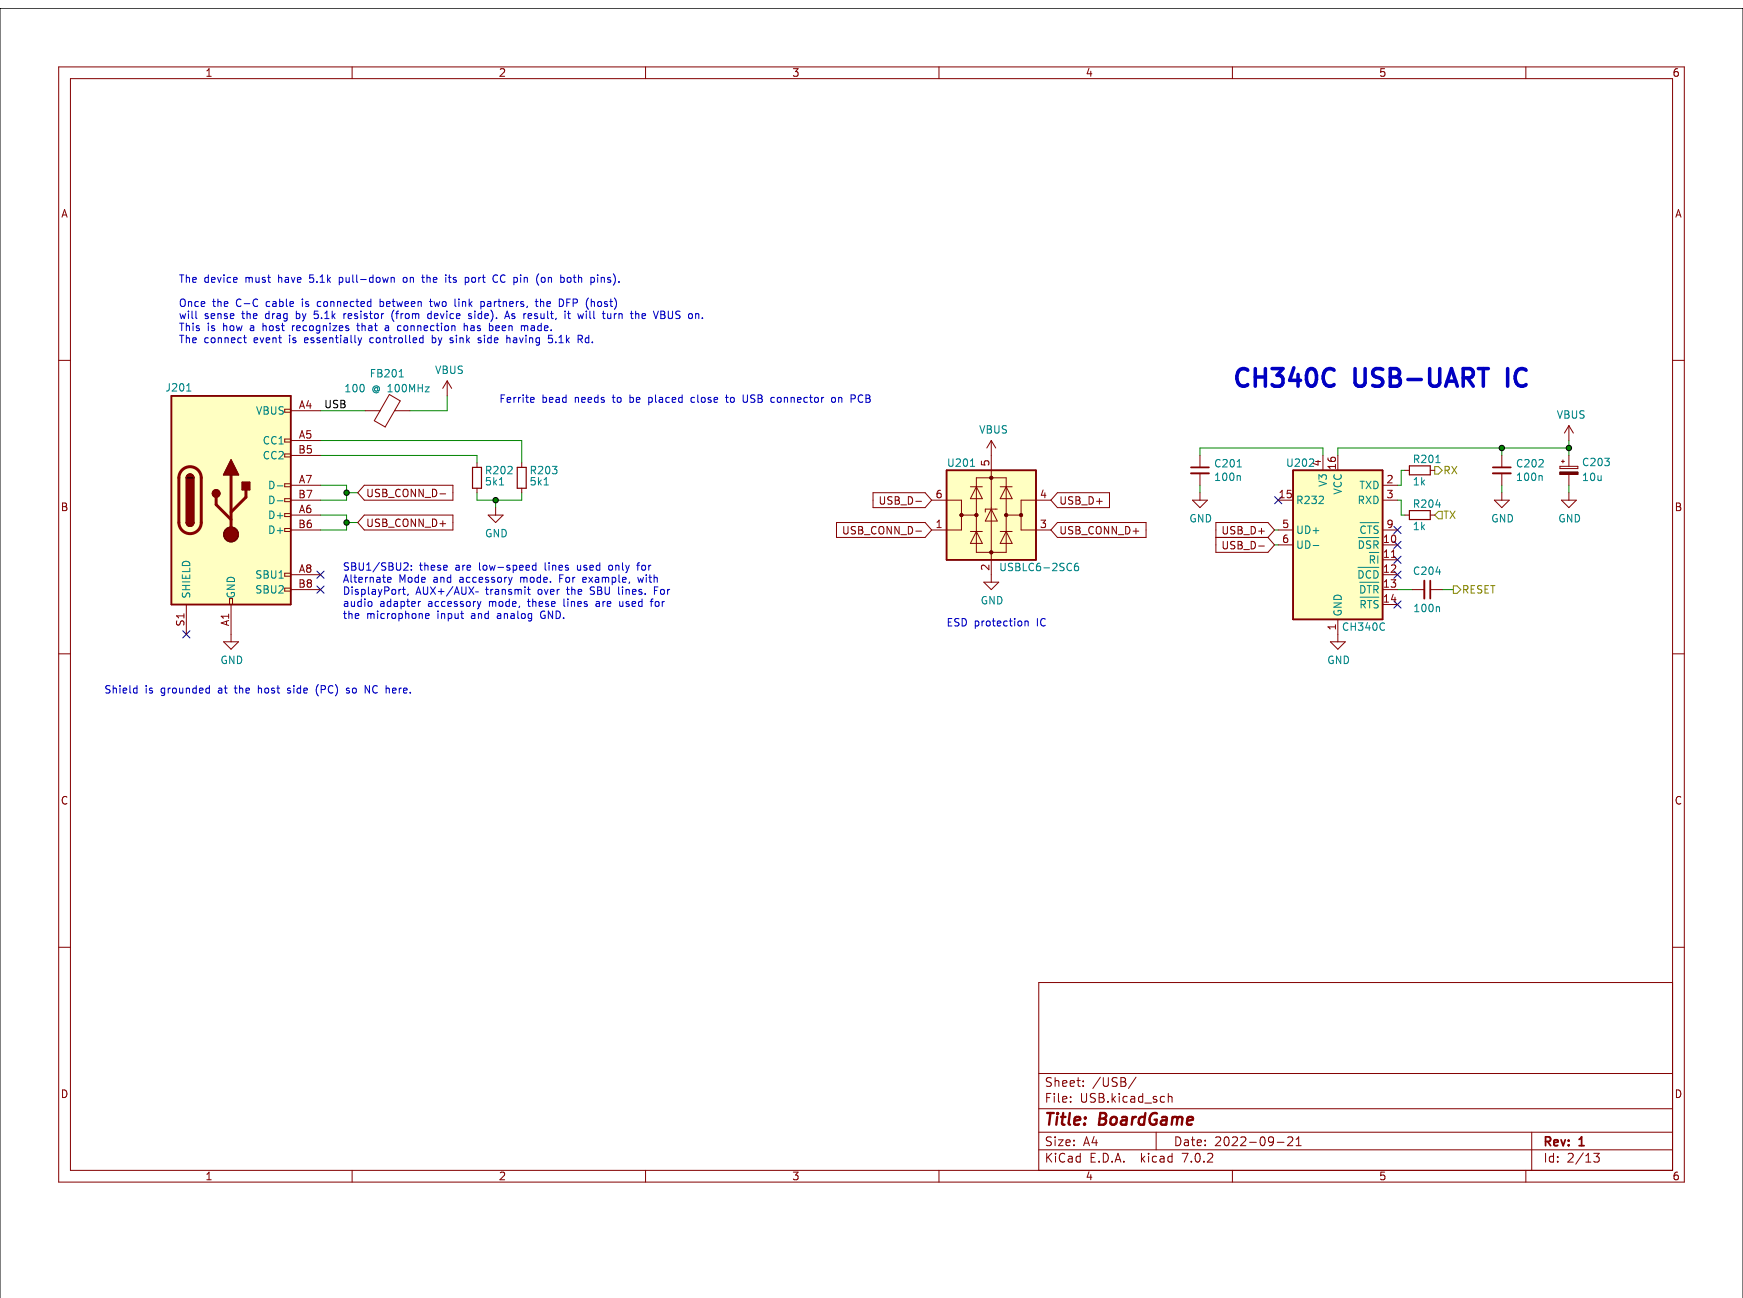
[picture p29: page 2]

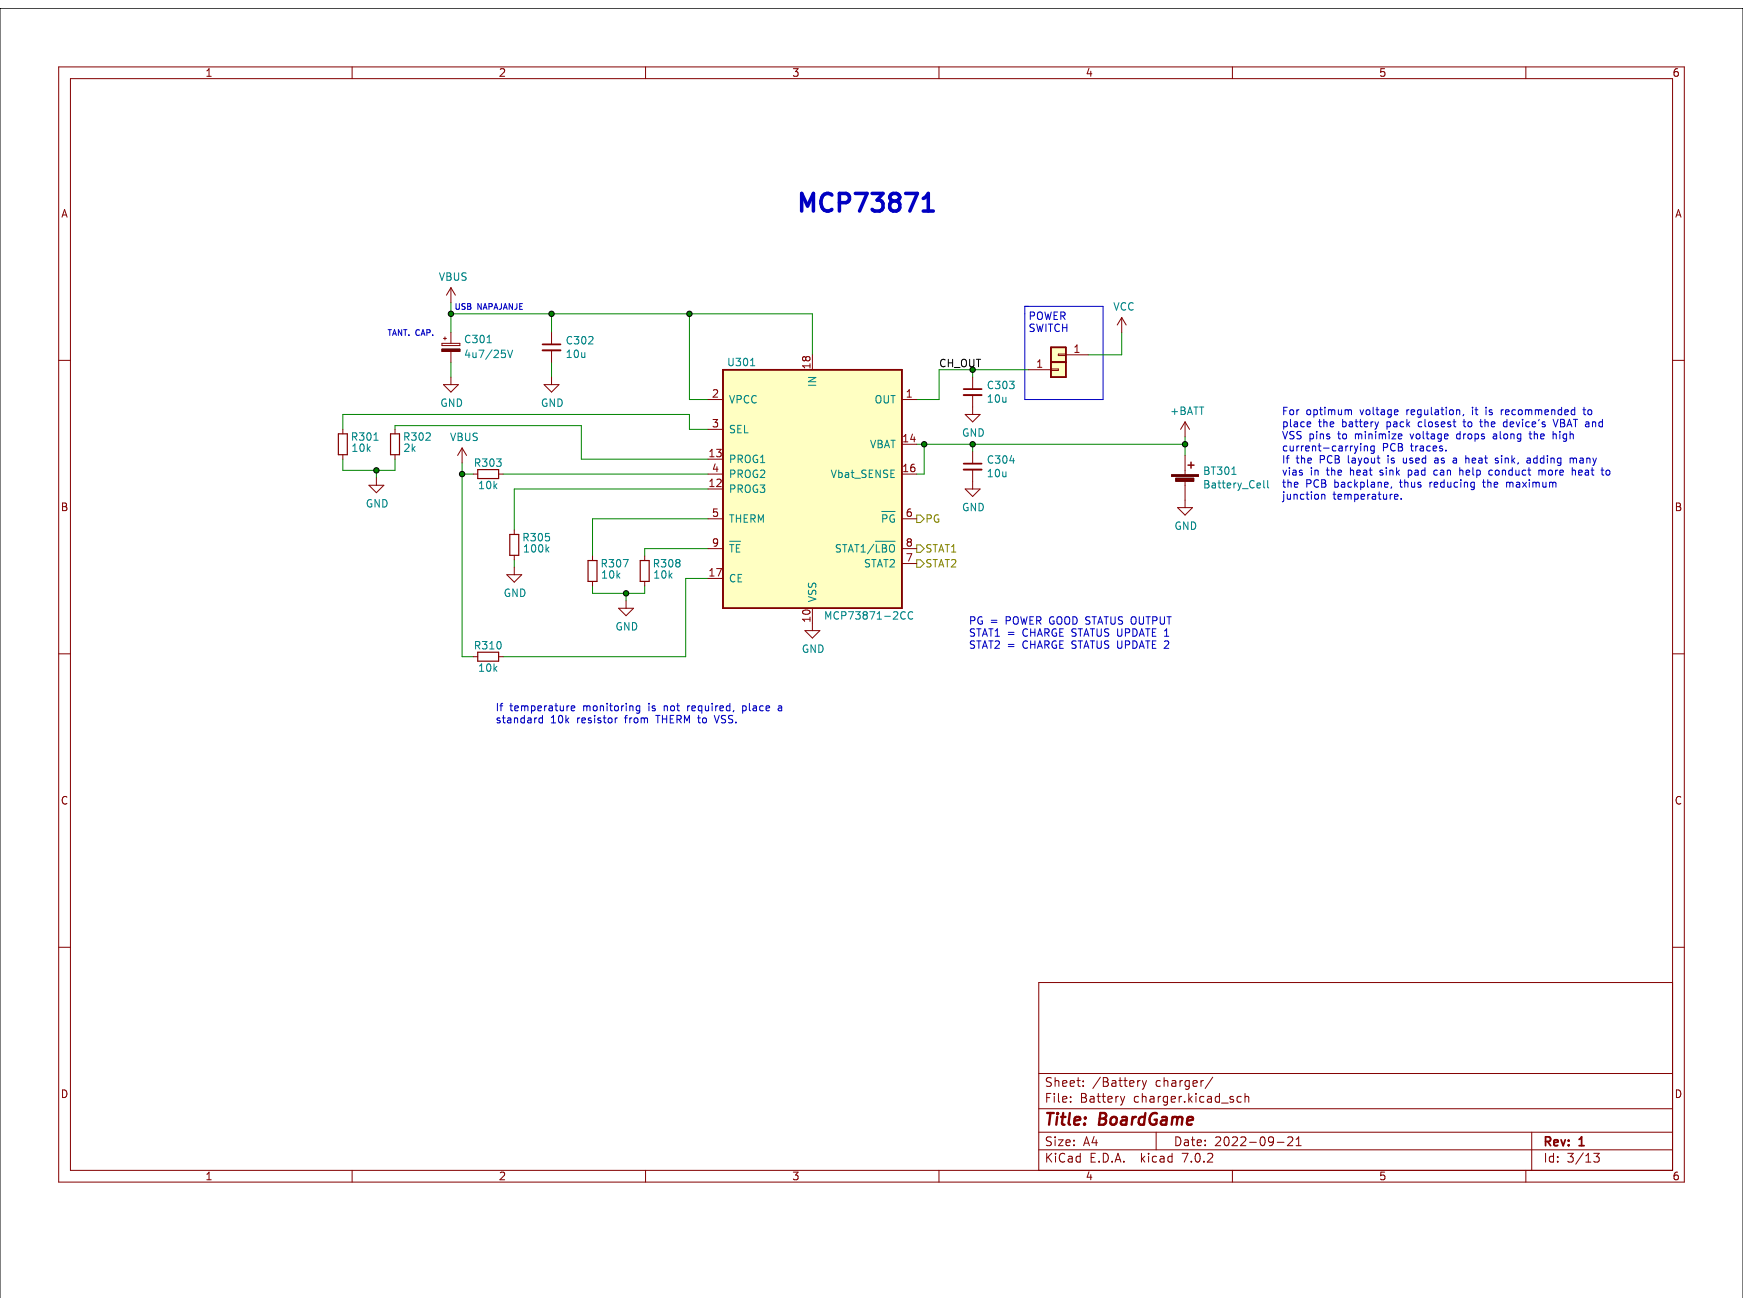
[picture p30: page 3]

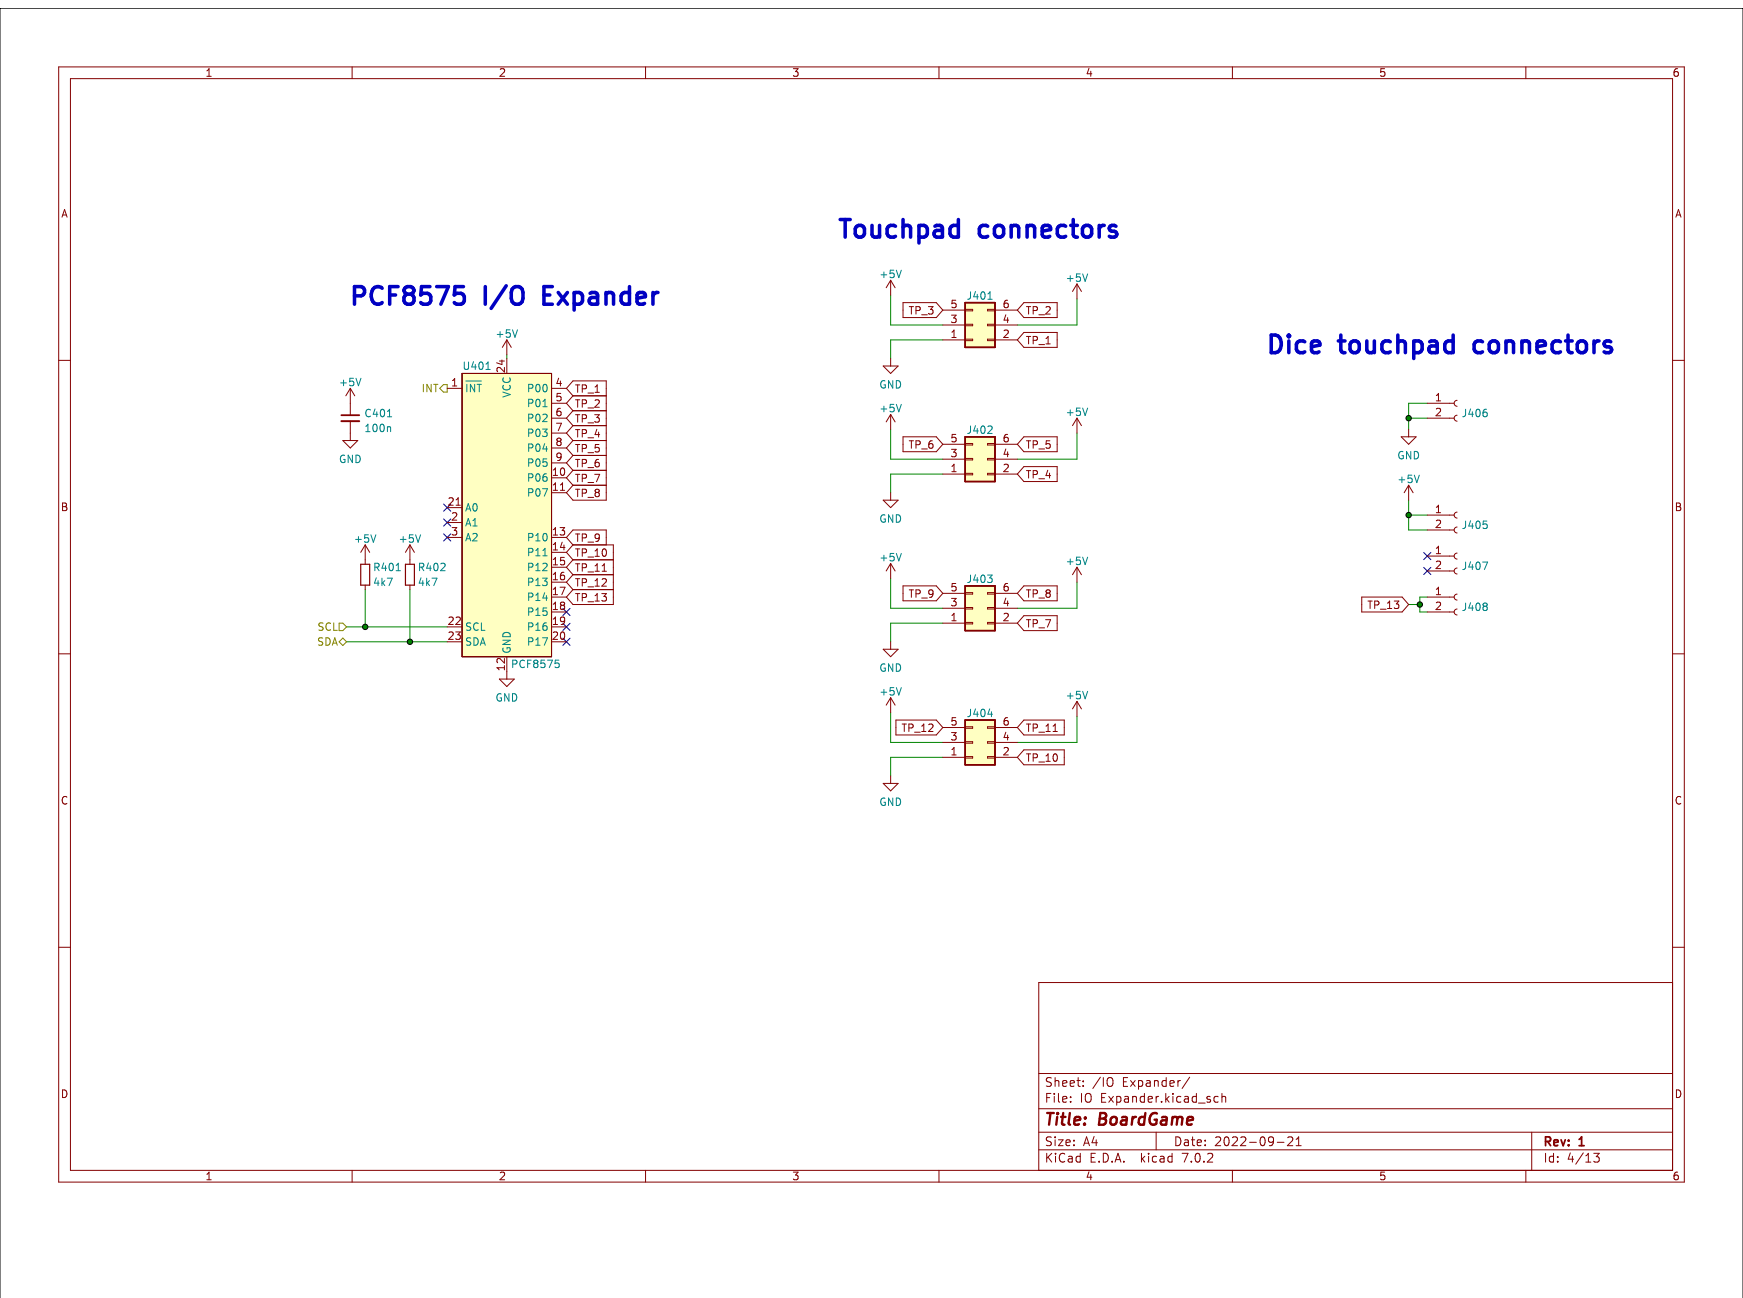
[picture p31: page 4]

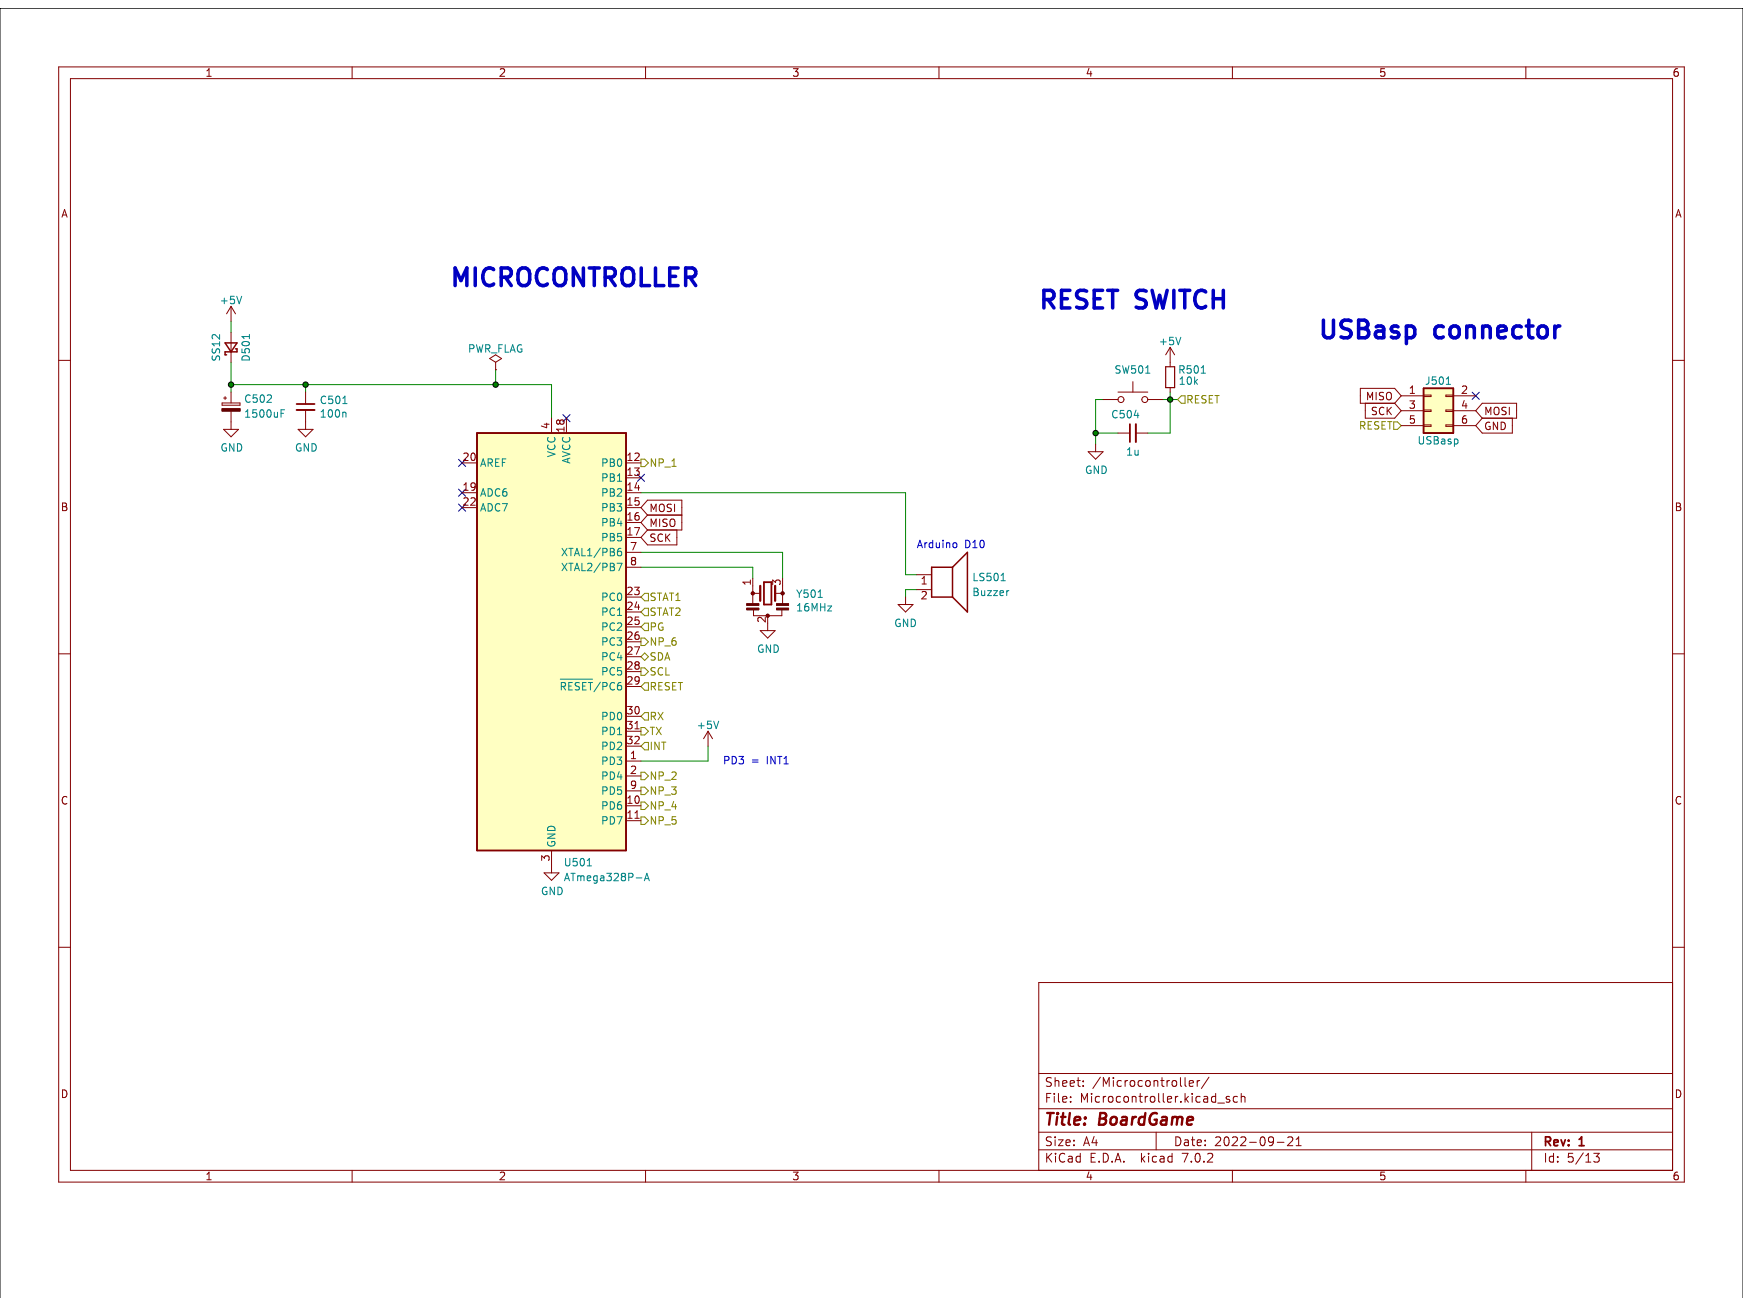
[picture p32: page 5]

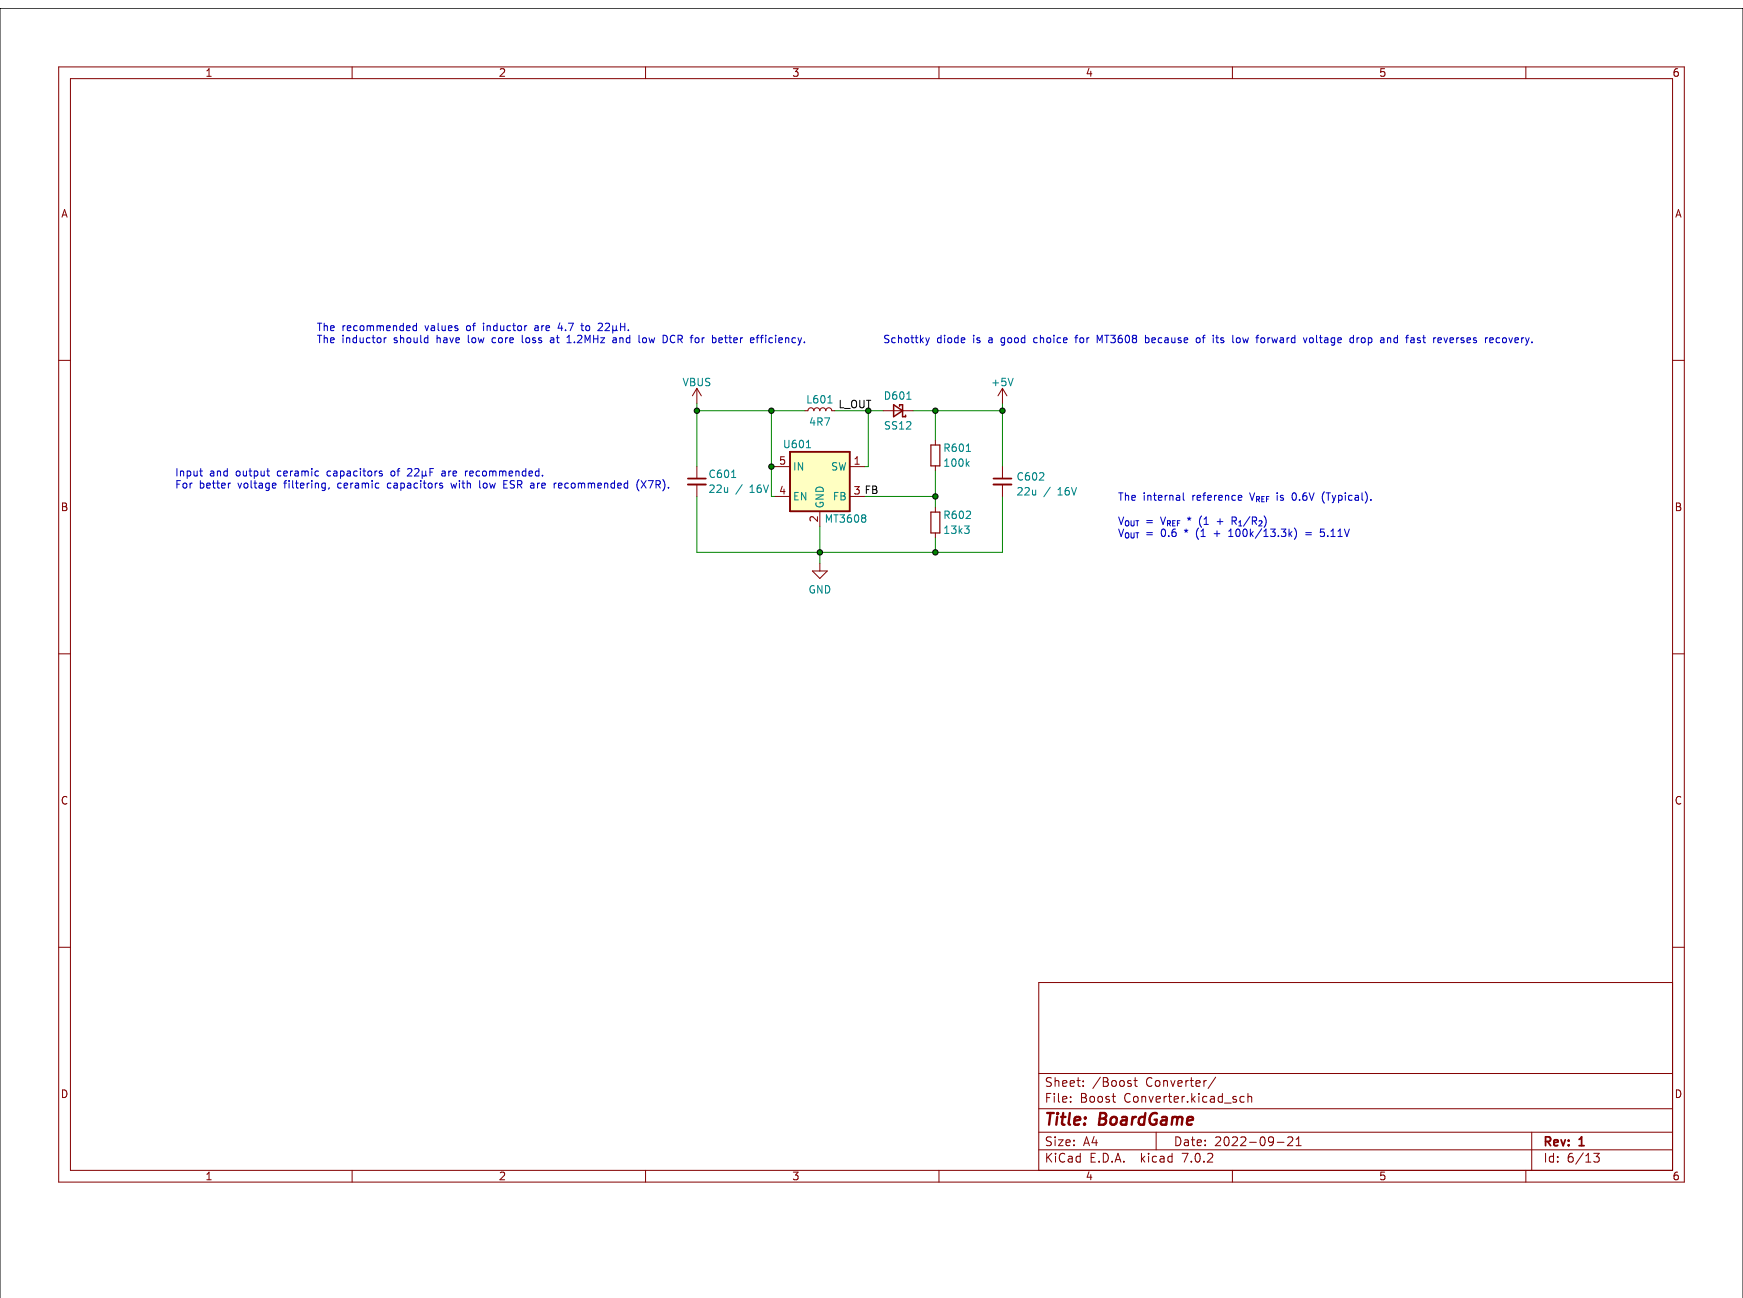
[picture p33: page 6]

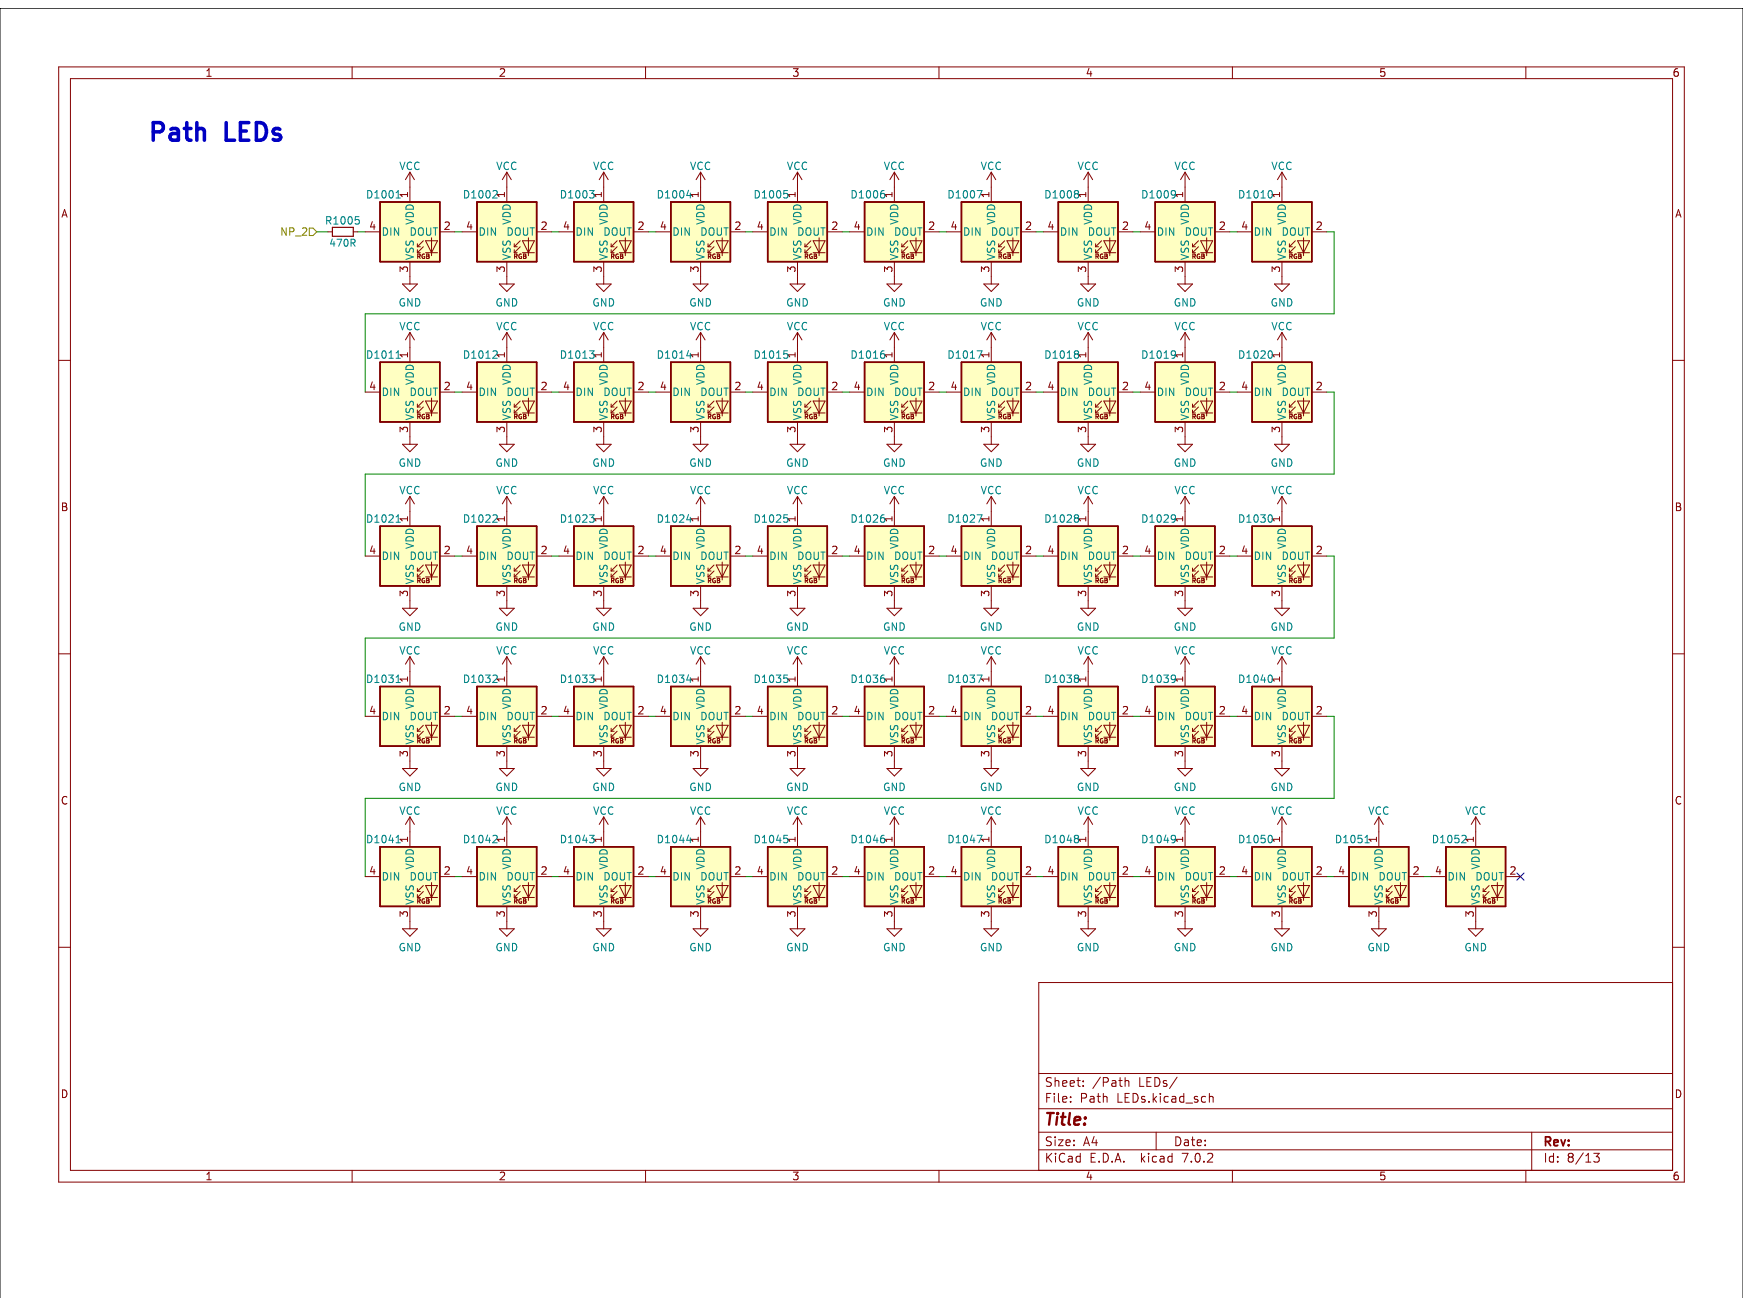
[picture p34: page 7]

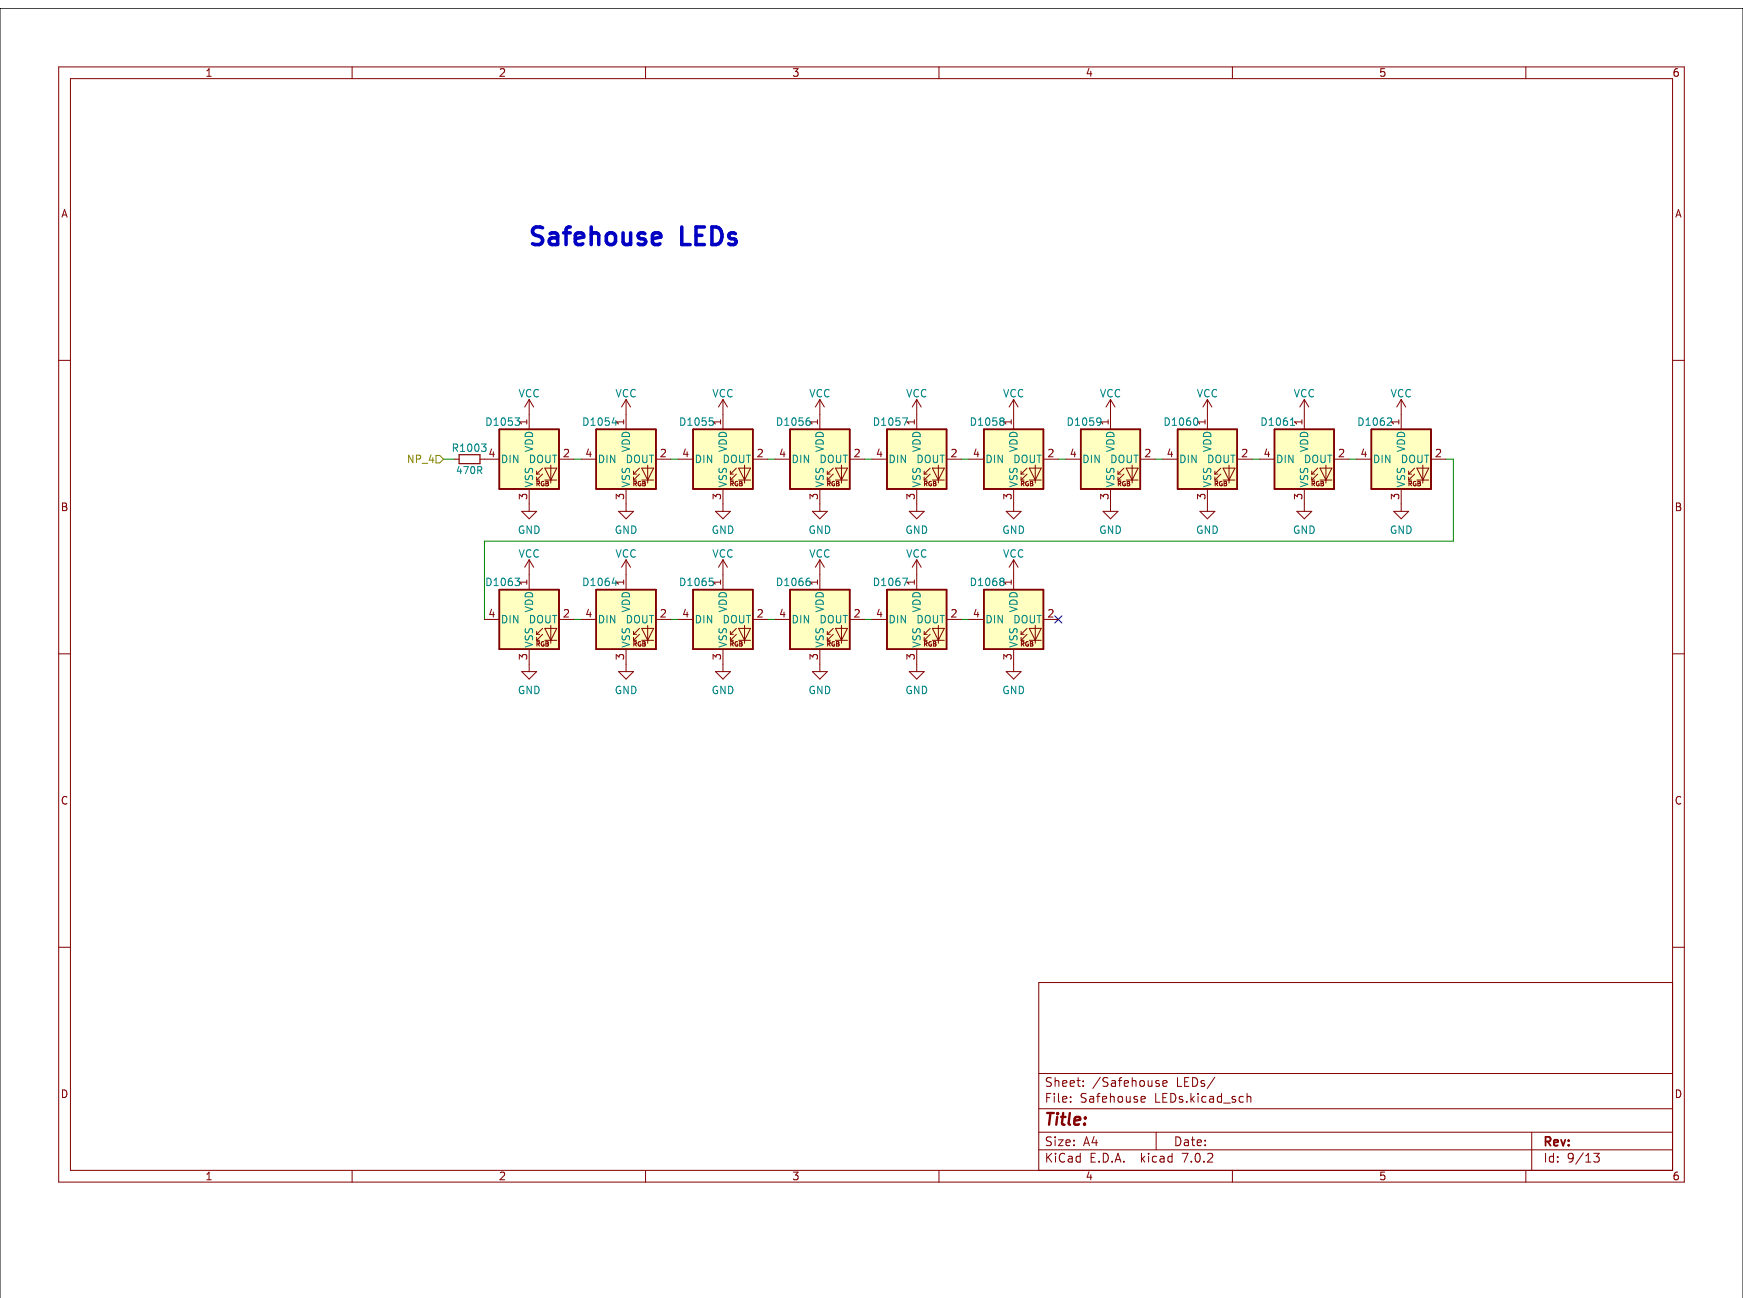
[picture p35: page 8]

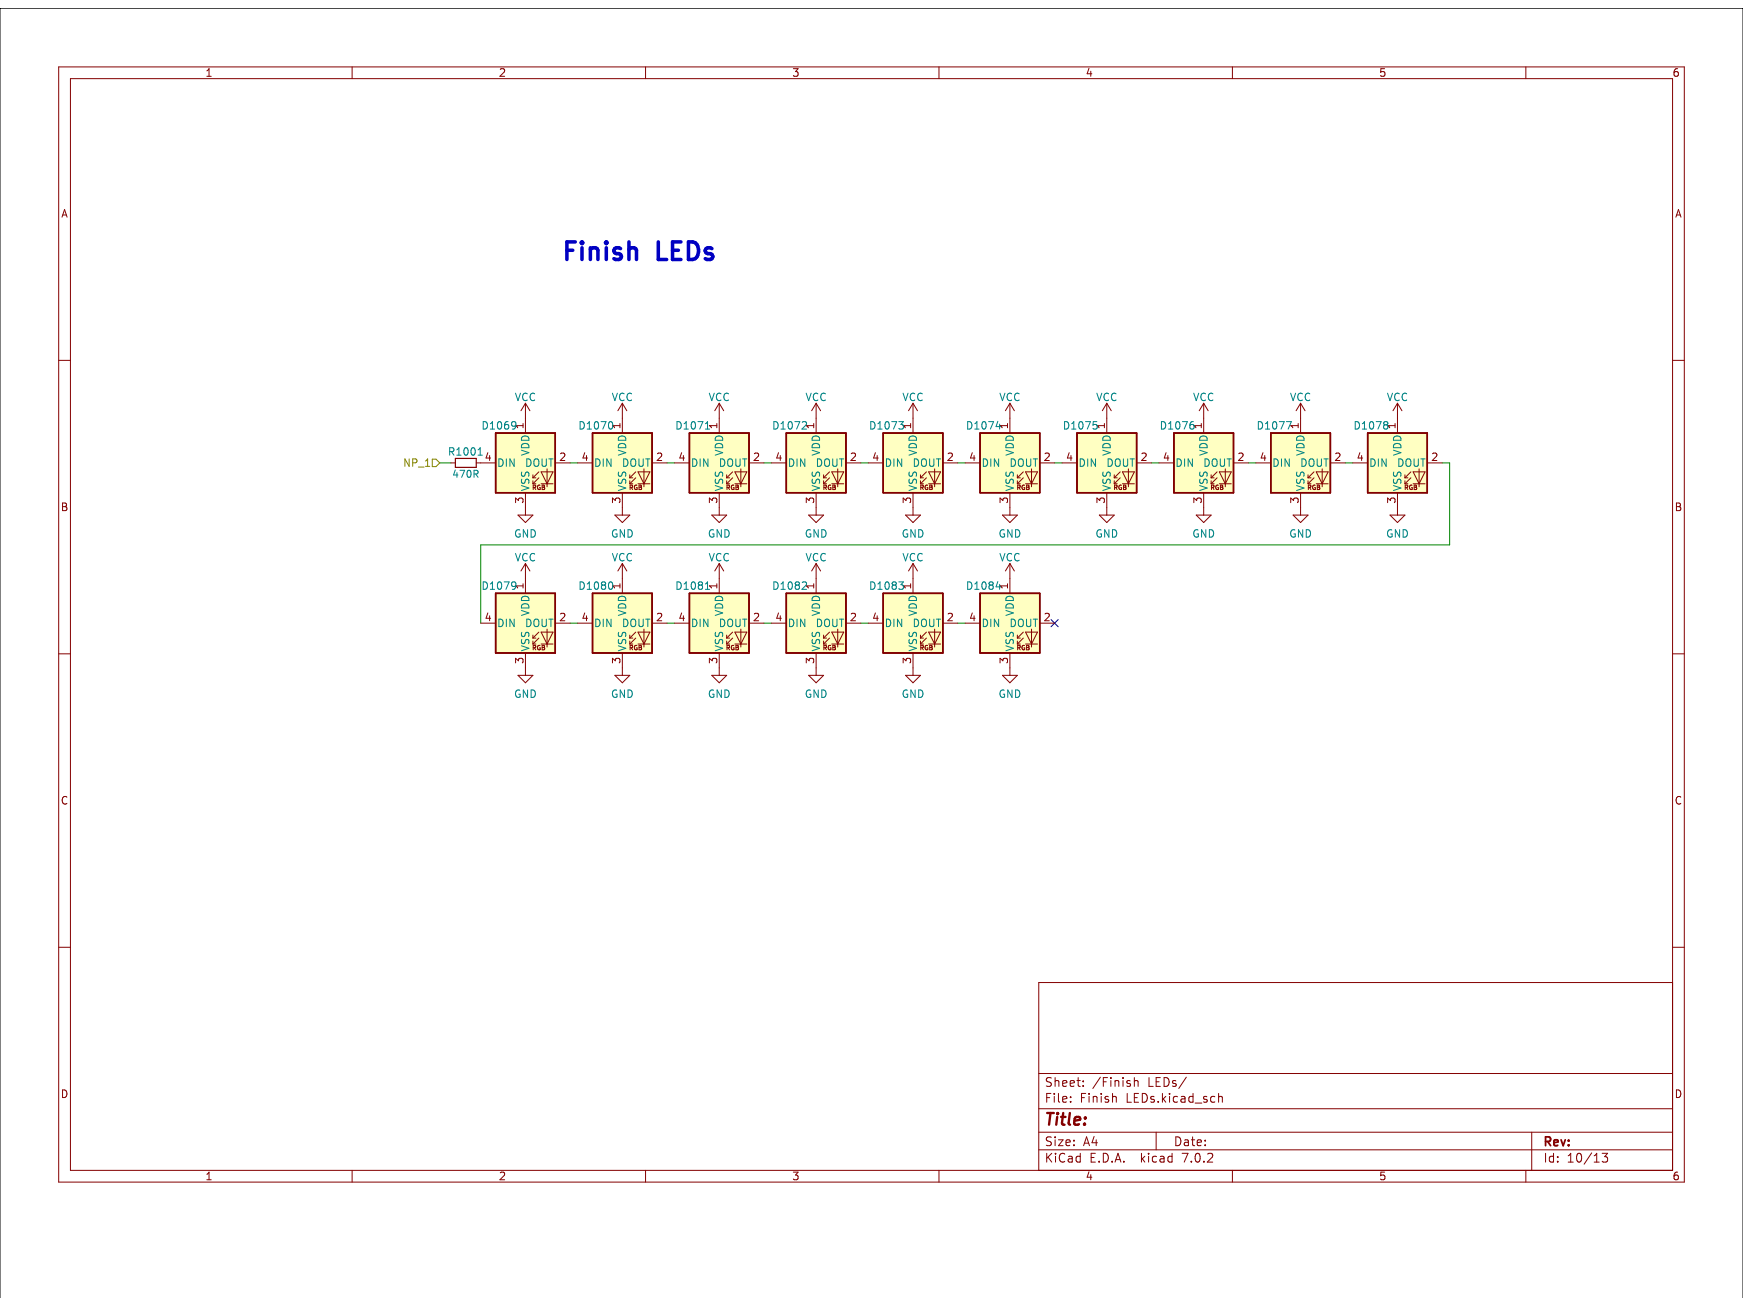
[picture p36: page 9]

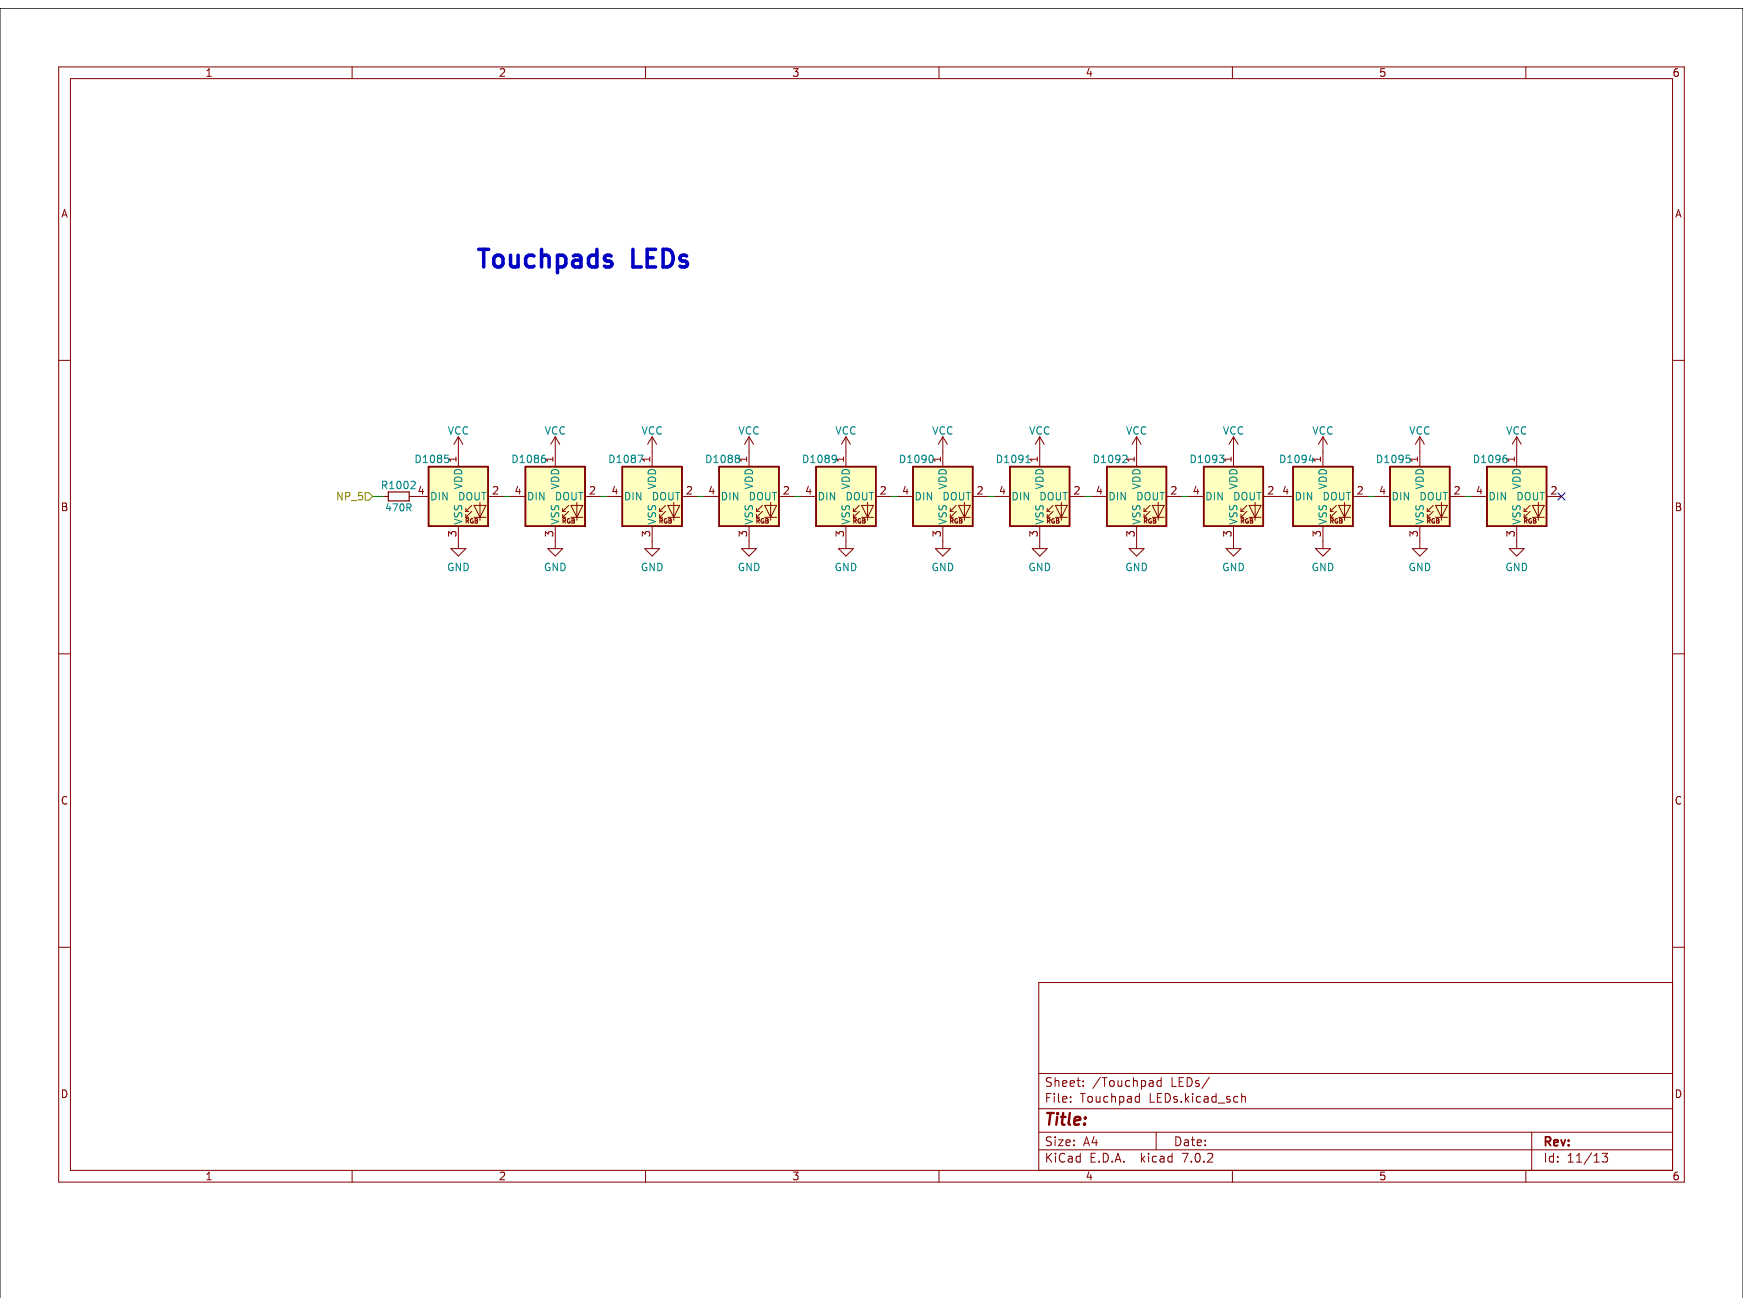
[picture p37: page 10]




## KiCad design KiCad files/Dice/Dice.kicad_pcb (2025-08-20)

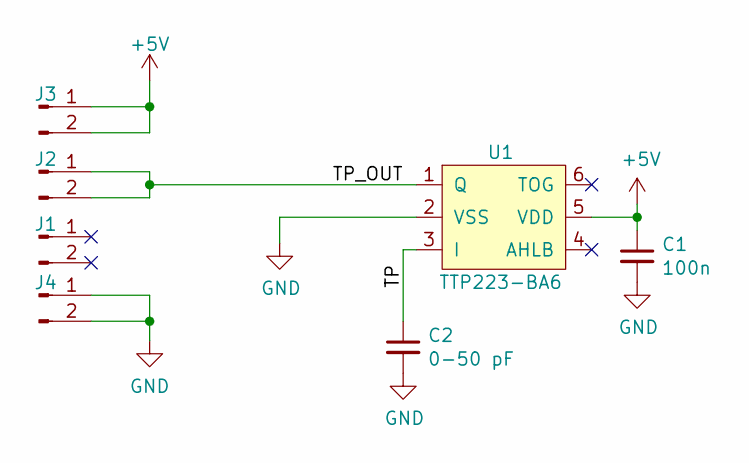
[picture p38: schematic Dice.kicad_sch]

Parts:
C1: 100n; C_0603_1608Metric
C2: 0-50 pF; C_0603_1608Metric
J1, J2, J3, J4: Conn_01x02_Male; PinHeader_1x02_P1.27mm_Vertical_SMD_Pin1Left
U1: TTP223-BA6; SOT-23-6

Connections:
+5V: C1.1, J3.1, J3.2, U1.5 (VDD)
/TP: C2.1, U1.3 (I)
/TP_OUT: J2.1, J2.2, U1.1 (Q)
GND: C1.2, C2.2, J4.1, J4.2, U1.2 (VSS)

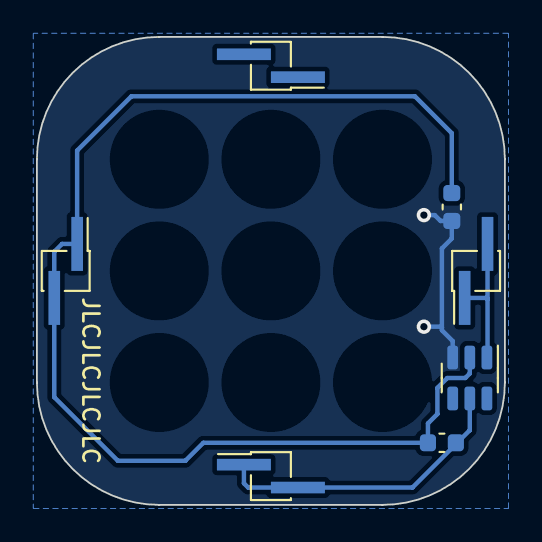
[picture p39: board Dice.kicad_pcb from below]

Board: 2 copper layers, 26.0 x 26.0 mm, 7 parts (7 on the bottom side), 4 nets.

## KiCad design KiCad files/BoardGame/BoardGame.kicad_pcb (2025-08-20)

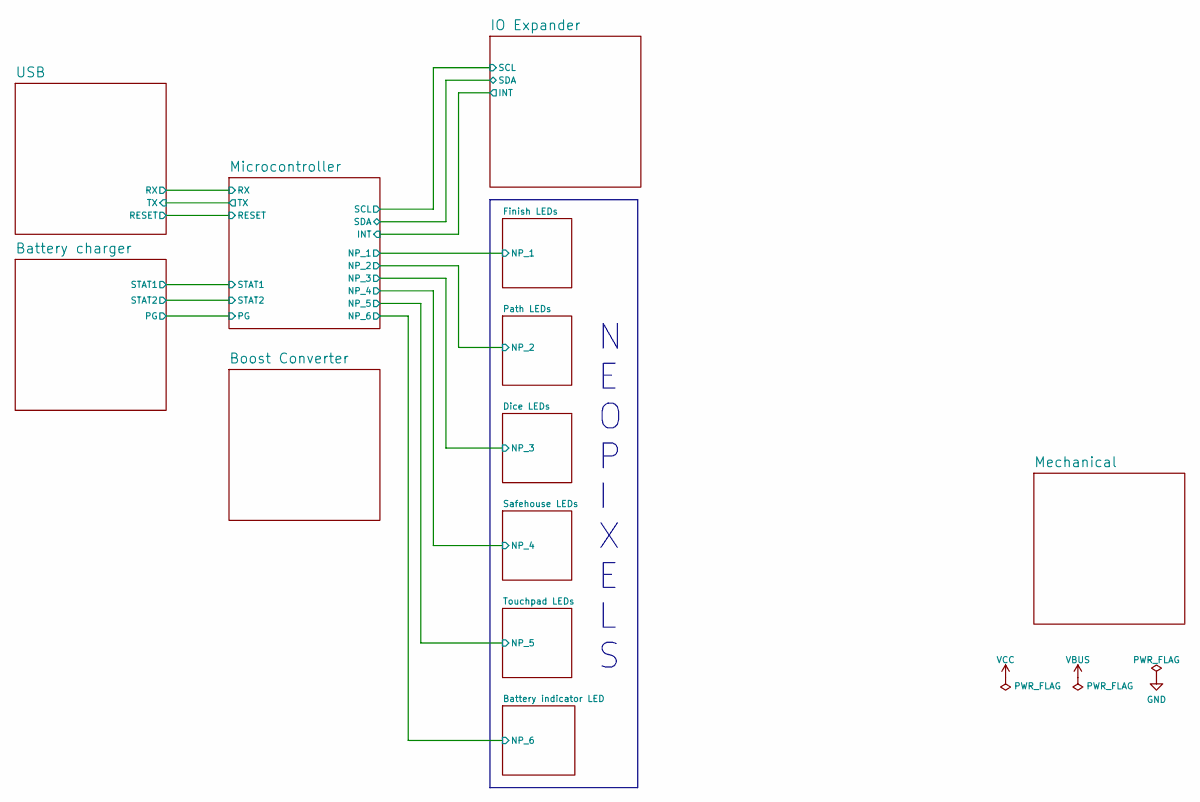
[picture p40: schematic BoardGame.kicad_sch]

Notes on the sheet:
N E O P I X E L S

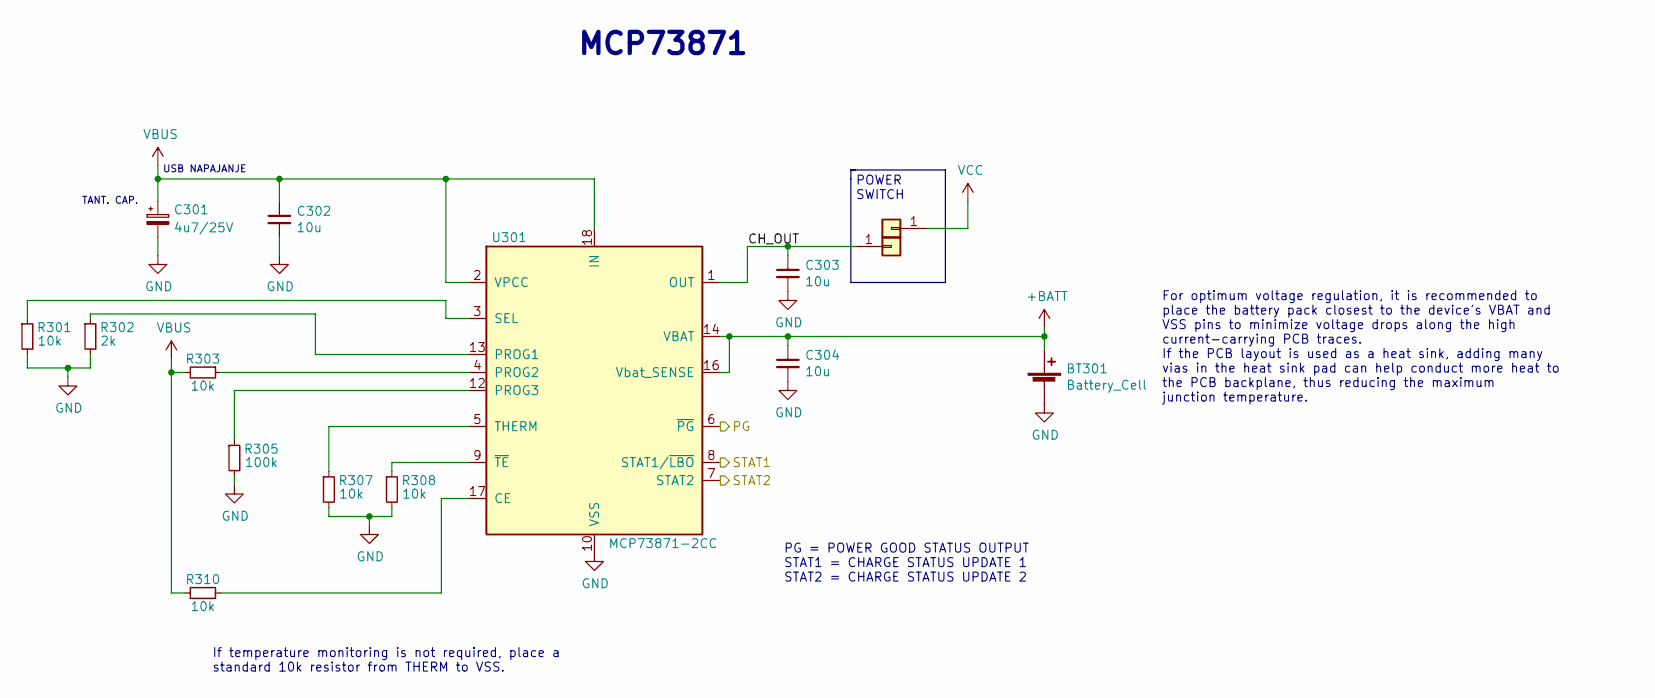
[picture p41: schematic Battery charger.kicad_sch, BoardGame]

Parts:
BT301: Battery_Cell; battery_103565_3000mah
C301: 4u7/25V; CP_EIA-3528-21_Kemet-B; JLCPCB Part # C2798040
C302, C303, C304: 10u; C_0805_2012Metric; JLCPCB Part # C237493
J301, J302: Conn_01x01; PinHeader_1x01
R301, R303, R307, R308, R310: 10k; R_0603_1608Metric
R302: 2k; R_0603_1608Metric; JLCPCB Part # C25590
R305: 100k; R_0603_1608Metric
U301: MCP73871-2CC; QFN-20-1EP_4x4mm_P0.5mm_EP2.5x2.5mm

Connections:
+BATT: BT301.1 (+), C304.1, U301.14 (VBAT), U301.15 (VBAT), U301.16 (Vbat_SENSE)
/Battery charger/CH_OUT: C303.1, J302.1, U301.1 (OUT), U301.20 (OUT)
/Battery charger/PG: U301.6 (~PG); also elsewhere on the board
/Battery charger/STAT1: U301.8 (STAT1/~LBO); also elsewhere on the board
/Battery charger/STAT2: U301.7 (STAT2); also elsewhere on the board
GND: BT301.2 (-), C301.2, C302.2, C303.2, C304.2, R301.2, R302.2, R305.2, R307.2, R308.2, U301.10 (VSS), U301.11 (VSS), U301.21 (VSS); also elsewhere on the board
unnamed: R310.2, U301.17 (CE)
unnamed: R302.1, U301.13 (PROG1)
unnamed: R303.1, U301.4 (PROG2)
unnamed: R305.1, U301.12 (PROG3)
unnamed: R301.1, U301.3 (SEL)
unnamed: R307.1, U301.5 (THERM)
unnamed: R308.1, U301.9 (~TE)
VBUS: C301.1, C302.1, R303.2, R310.1, U301.2 (VPCC), U301.18 (IN), U301.19 (IN); also elsewhere on the board
VCC: J301.1; also elsewhere on the board

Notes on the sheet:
PG = POWER GOOD STATUS OUTPUT STAT1 = CHARGE STATUS UPDATE 1 STAT2 = CHARGE STATUS UPDATE 2
TANT. CAP.
USB NAPAJANJE
POWER SWITCH
For optimum voltage regulation, it is recommended to place the battery pack closest to the device's VBAT and VSS pins to minimize voltage drops along the high current-carrying PCB traces. If the PCB layout is used as a heat sink, adding many vias in the heat sink pad can help conduct more heat to t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
MCP73871
If temperature monitoring is not required, place a standard 10k resistor from THERM to VSS.

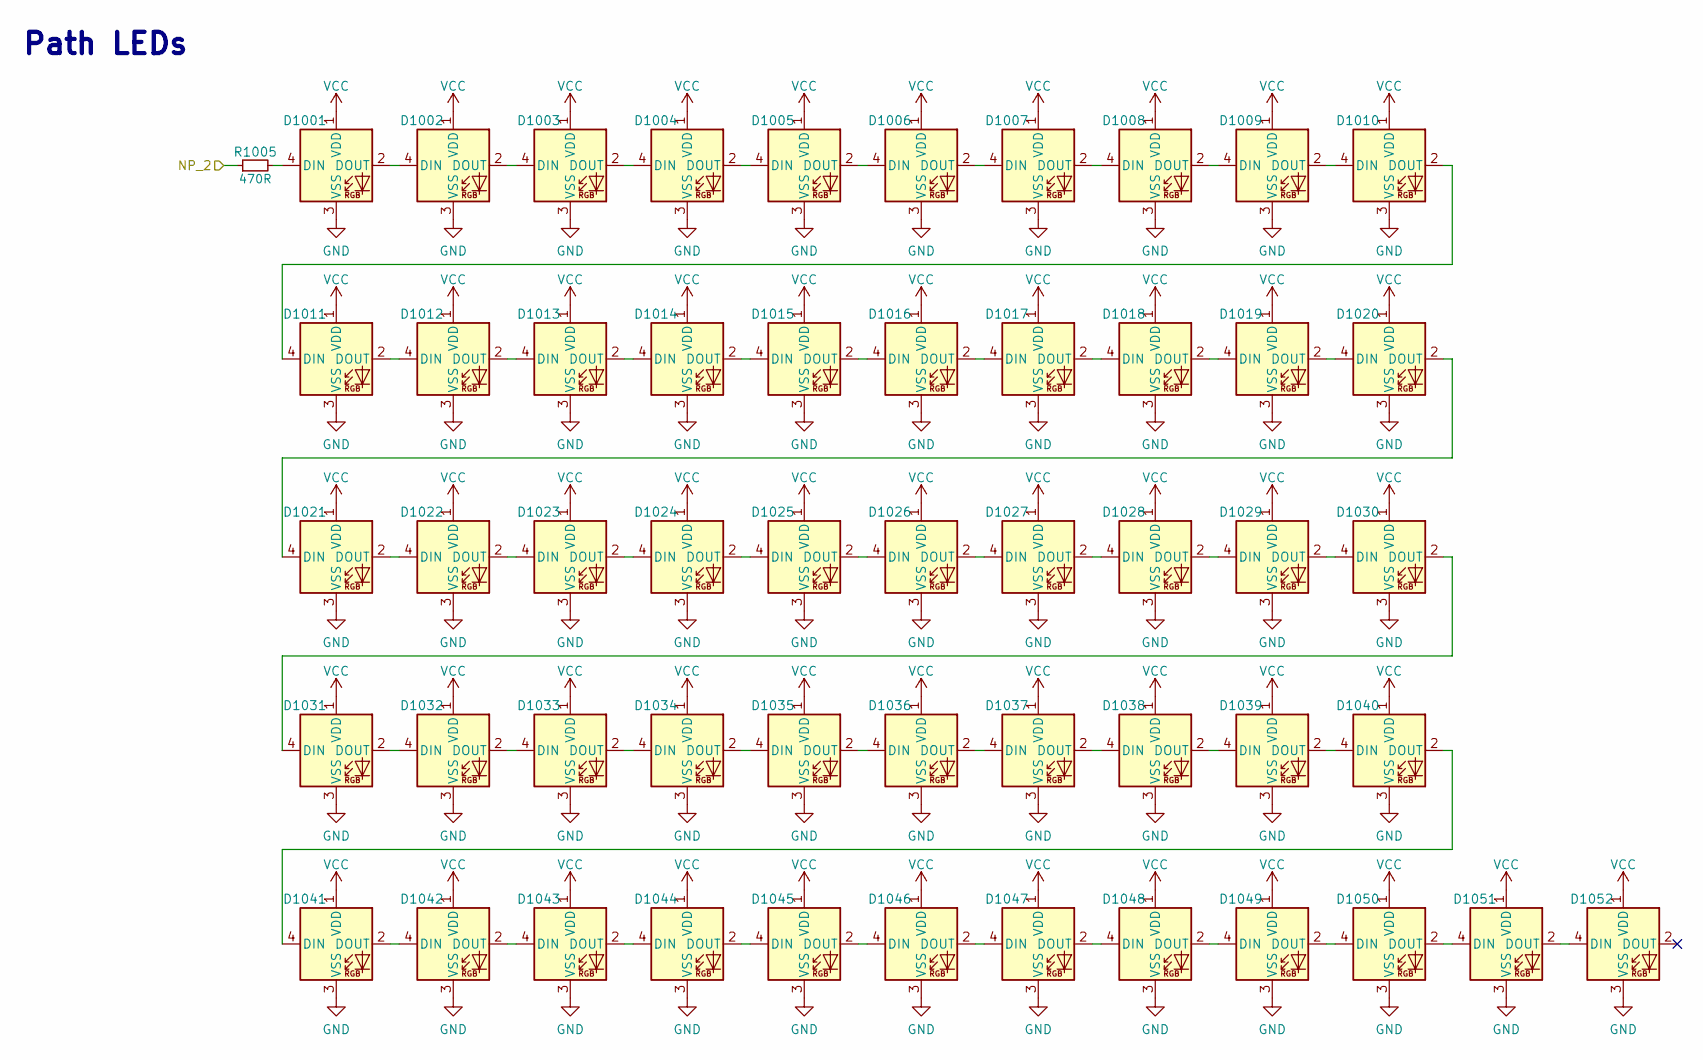
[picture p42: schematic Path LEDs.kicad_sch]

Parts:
D1001, D1002, D1003, D1004, D1005, D1006, D1007, D1008, D1009, D1010, D1011, D1012, D1013, D1014, D1015, D1016, D1017, D1018, D1019, D1020, D1021, D1022, D1023, D1024, D1025, D1026, D1027, D1028, D1029, D1030, D1031, D1032, D1033, D1034, D1035, D1036, D1037, D1038, D1039, D1040, D1041, D1042, D1043, D1044, D1045, D1046, D1047, D1048, D1049, D1050, D1051, D1052: WS2812B; LED_WS2812B_edited
R1005: 470R; R_0603_1608Metric

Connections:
/Microcontroller/NP_2: R1005.1; also elsewhere on the board
GND: D1001.3 (VSS), D1002.3 (VSS), D1003.3 (VSS), D1004.3 (VSS), D1005.3 (VSS), D1006.3 (VSS), D1007.3 (VSS), D1008.3 (VSS), D1009.3 (VSS), D1010.3 (VSS), D1011.3 (VSS), D1012.3 (VSS), D1013.3 (VSS), D1014.3 (VSS), D1015.3 (VSS), D1016.3 (VSS), D1017.3 (VSS), D1018.3 (VSS), D1019.3 (VSS), D1020.3 (VSS), D1021.3 (VSS), D1022.3 (VSS), D1023.3 (VSS), D1024.3 (VSS), D1025.3 (VSS), D1026.3 (VSS), D1027.3 (VSS), D1028.3 (VSS), D1029.3 (VSS), D1030.3 (VSS), D1031.3 (VSS), D1032.3 (VSS), D1033.3 (VSS), D1034.3 (VSS), D1035.3 (VSS), D1036.3 (VSS), D1037.3 (VSS), D1038.3 (VSS), D1039.3 (VSS), D1040.3 (VSS), D1041.3 (VSS), D1042.3 (VSS), D1043.3 (VSS), D1044.3 (VSS), D1045.3 (VSS), D1046.3 (VSS), D1047.3 (VSS), D1048.3 (VSS), D1049.3 (VSS), D1050.3 (VSS), D1051.3 (VSS), D1052.3 (VSS); also elsewhere on the board
unnamed: D1001.4 (DIN), R1005.2
unnamed: D1001.2 (DOUT), D1002.4 (DIN)
unnamed: D1002.2 (DOUT), D1003.4 (DIN)
unnamed: D1003.2 (DOUT), D1004.4 (DIN)
unnamed: D1004.2 (DOUT), D1005.4 (DIN)
unnamed: D1005.2 (DOUT), D1006.4 (DIN)
unnamed: D1006.2 (DOUT), D1007.4 (DIN)
unnamed: D1007.2 (DOUT), D1008.4 (DIN)
unnamed: D1008.2 (DOUT), D1009.4 (DIN)
unnamed: D1009.2 (DOUT), D1010.4 (DIN)
unnamed: D1010.2 (DOUT), D1011.4 (DIN)
unnamed: D1011.2 (DOUT), D1012.4 (DIN)
unnamed: D1012.2 (DOUT), D1013.4 (DIN)
unnamed: D1013.2 (DOUT), D1014.4 (DIN)
unnamed: D1014.2 (DOUT), D1015.4 (DIN)
unnamed: D1015.2 (DOUT), D1016.4 (DIN)
unnamed: D1016.2 (DOUT), D1017.4 (DIN)
unnamed: D1017.2 (DOUT), D1018.4 (DIN)
unnamed: D1018.2 (DOUT), D1019.4 (DIN)
unnamed: D1019.2 (DOUT), D1020.4 (DIN)
unnamed: D1020.2 (DOUT), D1021.4 (DIN)
unnamed: D1021.2 (DOUT), D1022.4 (DIN)
unnamed: D1022.2 (DOUT), D1023.4 (DIN)
unnamed: D1023.2 (DOUT), D1024.4 (DIN)
unnamed: D1024.2 (DOUT), D1025.4 (DIN)
unnamed: D1025.2 (DOUT), D1026.4 (DIN)
unnamed: D1026.2 (DOUT), D1027.4 (DIN)
unnamed: D1027.2 (DOUT), D1028.4 (DIN)
unnamed: D1028.2 (DOUT), D1029.4 (DIN)
unnamed: D1029.2 (DOUT), D1030.4 (DIN)
unnamed: D1030.2 (DOUT), D1031.4 (DIN)
unnamed: D1031.2 (DOUT), D1032.4 (DIN)
unnamed: D1032.2 (DOUT), D1033.4 (DIN)
unnamed: D1033.2 (DOUT), D1034.4 (DIN)
unnamed: D1034.2 (DOUT), D1035.4 (DIN)
unnamed: D1035.2 (DOUT), D1036.4 (DIN)
unnamed: D1036.2 (DOUT), D1037.4 (DIN)
unnamed: D1037.2 (DOUT), D1038.4 (DIN)
unnamed: D1038.2 (DOUT), D1039.4 (DIN)
unnamed: D1039.2 (DOUT), D1040.4 (DIN)
unnamed: D1040.2 (DOUT), D1041.4 (DIN)
unnamed: D1041.2 (DOUT), D1042.4 (DIN)
unnamed: D1042.2 (DOUT), D1043.4 (DIN)
unnamed: D1043.2 (DOUT), D1044.4 (DIN)
unnamed: D1044.2 (DOUT), D1045.4 (DIN)
unnamed: D1045.2 (DOUT), D1046.4 (DIN)
unnamed: D1046.2 (DOUT), D1047.4 (DIN)
unnamed: D1047.2 (DOUT), D1048.4 (DIN)
unnamed: D1048.2 (DOUT), D1049.4 (DIN)
unnamed: D1049.2 (DOUT), D1050.4 (DIN)
unnamed: D1050.2 (DOUT), D1051.4 (DIN)
unnamed: D1051.2 (DOUT), D1052.4 (DIN)
VCC: D1001.1 (VDD), D1002.1 (VDD), D1003.1 (VDD), D1004.1 (VDD), D1005.1 (VDD), D1006.1 (VDD), D1007.1 (VDD), D1008.1 (VDD), D1009.1 (VDD), D1010.1 (VDD), D1011.1 (VDD), D1012.1 (VDD), D1013.1 (VDD), D1014.1 (VDD), D1015.1 (VDD), D1016.1 (VDD), D1017.1 (VDD), D1018.1 (VDD), D1019.1 (VDD), D1020.1 (VDD), D1021.1 (VDD), D1022.1 (VDD), D1023.1 (VDD), D1024.1 (VDD), D1025.1 (VDD), D1026.1 (VDD), D1027.1 (VDD), D1028.1 (VDD), D1029.1 (VDD), D1030.1 (VDD), D1031.1 (VDD), D1032.1 (VDD), D1033.1 (VDD), D1034.1 (VDD), D1035.1 (VDD), D1036.1 (VDD), D1037.1 (VDD), D1038.1 (VDD), D1039.1 (VDD), D1040.1 (VDD), D1041.1 (VDD), D1042.1 (VDD), D1043.1 (VDD), D1044.1 (VDD), D1045.1 (VDD), D1046.1 (VDD), D1047.1 (VDD), D1048.1 (VDD), D1049.1 (VDD), D1050.1 (VDD), D1051.1 (VDD), D1052.1 (VDD); also elsewhere on the board

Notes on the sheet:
Path LEDs

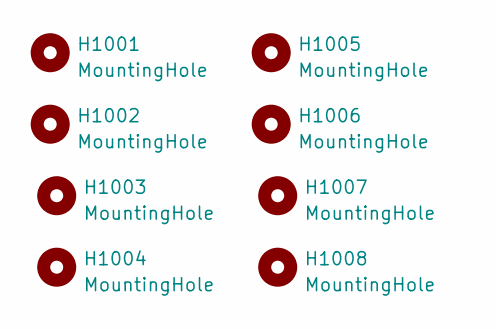
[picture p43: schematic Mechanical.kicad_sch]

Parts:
H1001, H1002, H1003, H1004, H1005, H1006, H1007, H1008: MountingHole; MountingHole_3.2mm_M3

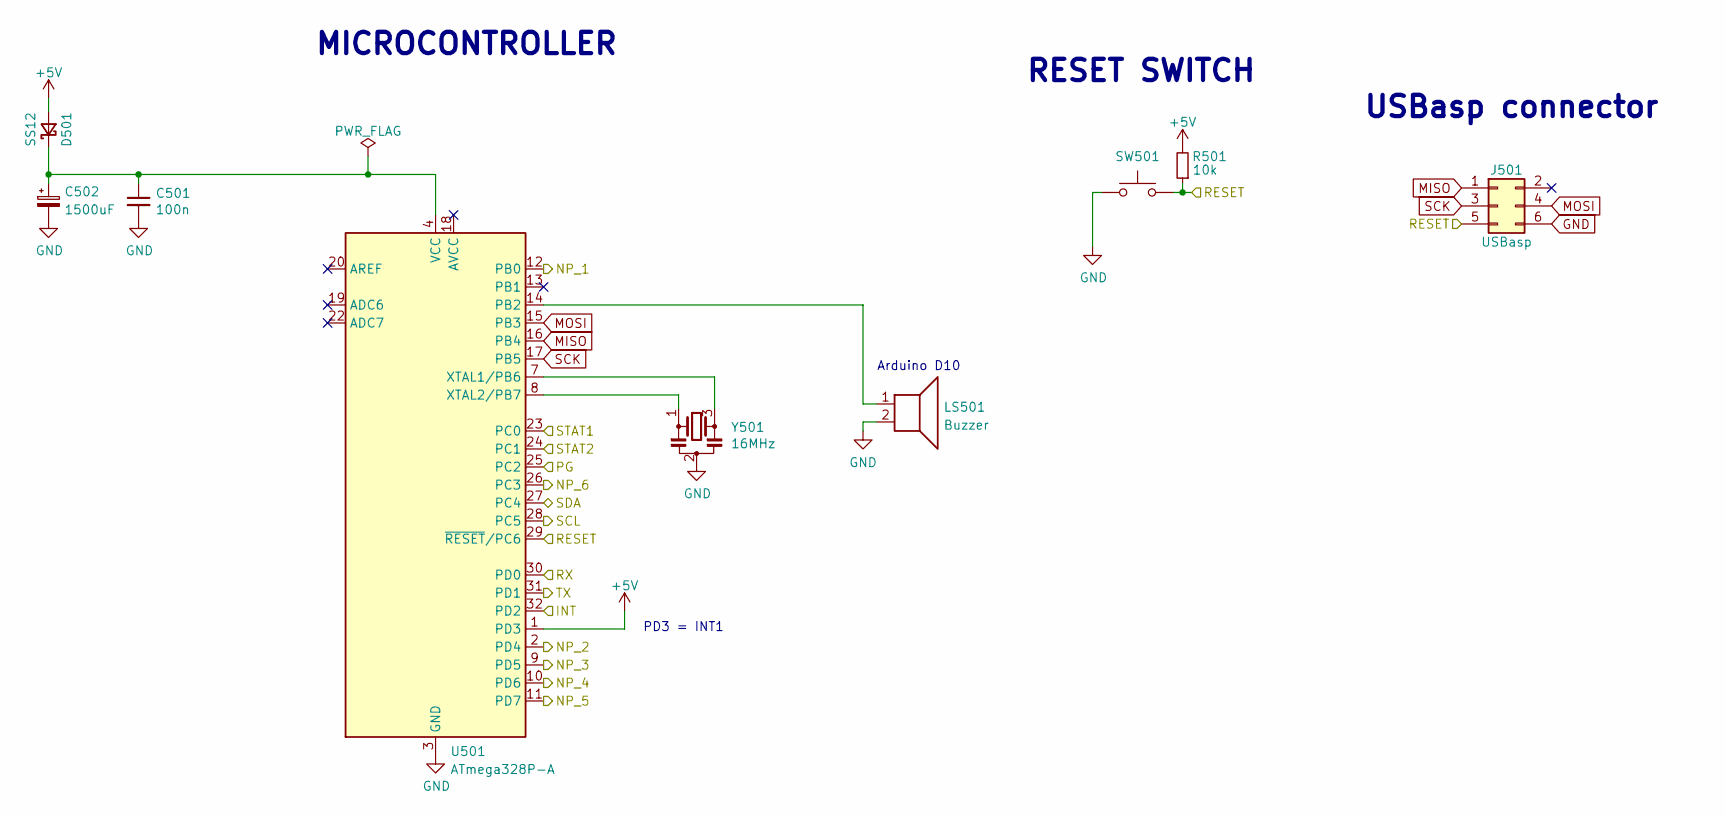
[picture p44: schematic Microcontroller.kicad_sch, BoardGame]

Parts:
C501: 100n; C_0603_1608Metric; JLCPCB Part # C113803
C502: 1500uF; CP_EIA-7343-31_Kemet-D
D501: SS12; D_SMA; JLCPCB Part # C2985002
J501: USBasp; PinHeader_2x03_P1.27mm_Vertical_SMD
LS501: Buzzer; KLJ-1102
R501: 10k; R_0603_1608Metric
SW501: SW_Push; SW_SPST_TL3342; JLCPCB Part # C2886894
U501: ATmega328P-A; TQFP-32_7x7mm_P0.8mm
Y501: 16MHz; CSTCE16M0V53-R0; JLCPCB Part # C32180

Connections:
+5V: D501.2 (A), R501.2, U501.1 (PD3); also elsewhere on the board
/Battery charger/PG: U501.25 (PC2); also elsewhere on the board
/Battery charger/STAT1: U501.23 (PC0); also elsewhere on the board
/Battery charger/STAT2: U501.24 (PC1); also elsewhere on the board
/Battery indicator LED/NP_6: U501.26 (PC3); also elsewhere on the board
/Dice LEDs/NP_3: U501.9 (PD5); also elsewhere on the board
/Finish LEDs/NP_1: U501.12 (PB0); also elsewhere on the board
/IO Expander/INT: U501.32 (PD2); also elsewhere on the board
/IO Expander/SCL: U501.28 (PC5); also elsewhere on the board
/IO Expander/SDA: U501.27 (PC4); also elsewhere on the board
/Microcontroller/NP_2: U501.2 (PD4); also elsewhere on the board
/Microcontroller/NP_4: U501.10 (PD6); also elsewhere on the board
/Microcontroller/NP_5: U501.11 (PD7); also elsewhere on the board
/Microcontroller/RESET: J501.5, R501.1, SW501.2, U501.29 (~RESET/PC6); also elsewhere on the board
/Microcontroller/RX: U501.30 (PD0); also elsewhere on the board
/Microcontroller/TX: U501.31 (PD1); also elsewhere on the board
GND: C501.2, C502.2, J501.6, LS501.2, SW501.1, U501.3 (GND), U501.5 (GND), U501.21 (GND), Y501.2; also elsewhere on the board
MISO: J501.1, U501.16 (PB4)
MOSI: J501.4, U501.15 (PB3)
unnamed: C501.1, C502.1, D501.1 (K), U501.4 (VCC), U501.6 (VCC)
unnamed: LS501.1, U501.14 (PB2)
unnamed: U501.7 (XTAL1/PB6), Y501.3
unnamed: U501.8 (XTAL2/PB7), Y501.1
SCK: J501.3, U501.17 (PB5)

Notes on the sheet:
MICROCONTROLLER
USBasp connector
PD3 = INT1
Arduino D10
RESET SWITCH

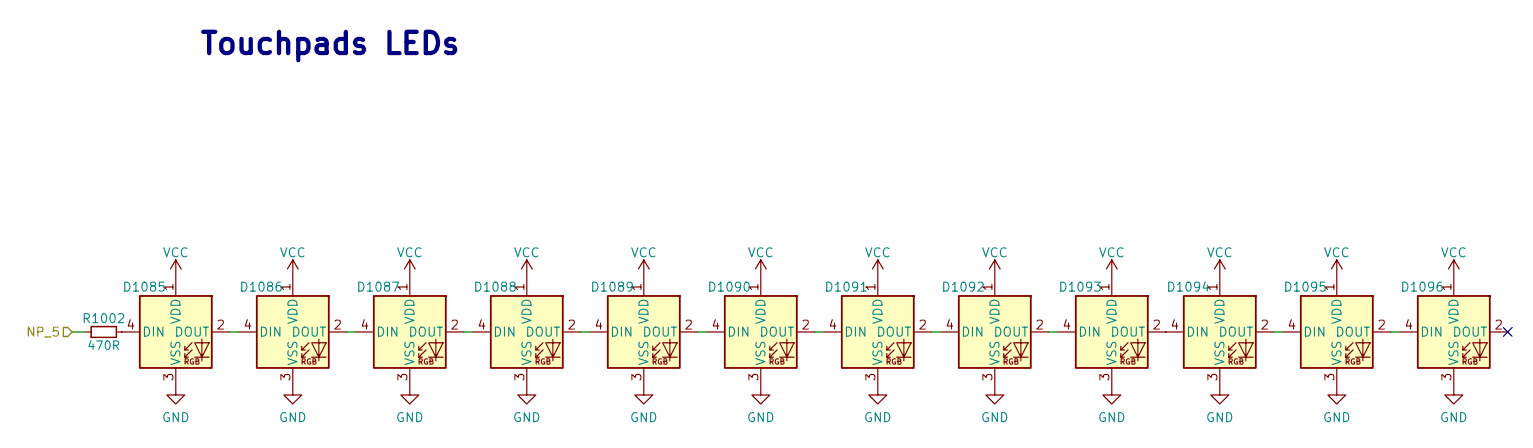
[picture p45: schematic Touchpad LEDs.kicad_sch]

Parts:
D1085, D1086, D1087, D1088, D1089, D1090, D1091, D1092, D1093, D1094, D1095, D1096: WS2812B; LED_WS2812B_edited
R1002: 470R; R_0603_1608Metric

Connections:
/Microcontroller/NP_5: R1002.1; also elsewhere on the board
GND: D1085.3 (VSS), D1086.3 (VSS), D1087.3 (VSS), D1088.3 (VSS), D1089.3 (VSS), D1090.3 (VSS), D1091.3 (VSS), D1092.3 (VSS), D1093.3 (VSS), D1094.3 (VSS), D1095.3 (VSS), D1096.3 (VSS); also elsewhere on the board
unnamed: D1085.4 (DIN), R1002.2
unnamed: D1085.2 (DOUT), D1086.4 (DIN)
unnamed: D1086.2 (DOUT), D1087.4 (DIN)
unnamed: D1087.2 (DOUT), D1088.4 (DIN)
unnamed: D1088.2 (DOUT), D1089.4 (DIN)
unnamed: D1089.2 (DOUT), D1090.4 (DIN)
unnamed: D1090.2 (DOUT), D1091.4 (DIN)
unnamed: D1091.2 (DOUT), D1092.4 (DIN)
unnamed: D1092.2 (DOUT), D1093.4 (DIN)
unnamed: D1093.2 (DOUT), D1094.4 (DIN)
unnamed: D1094.2 (DOUT), D1095.4 (DIN)
unnamed: D1095.2 (DOUT), D1096.4 (DIN)
VCC: D1085.1 (VDD), D1086.1 (VDD), D1087.1 (VDD), D1088.1 (VDD), D1089.1 (VDD), D1090.1 (VDD), D1091.1 (VDD), D1092.1 (VDD), D1093.1 (VDD), D1094.1 (VDD), D1095.1 (VDD), D1096.1 (VDD); also elsewhere on the board

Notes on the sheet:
Touchpads LEDs

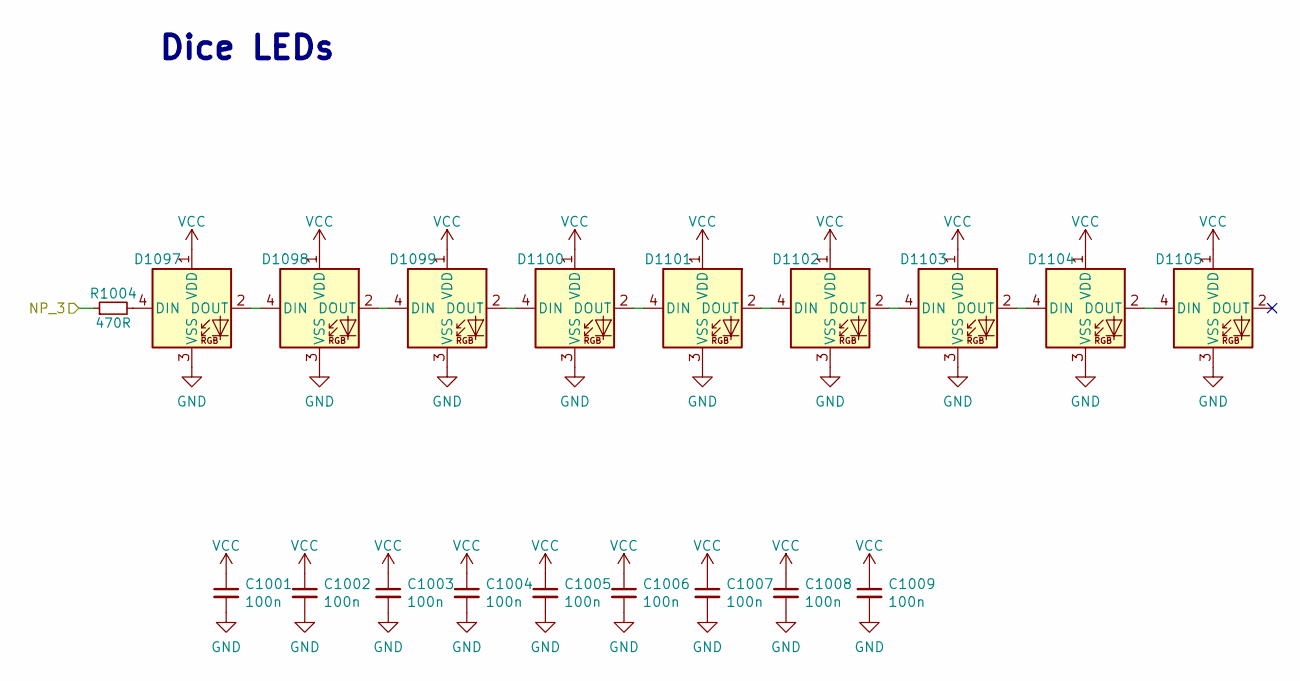
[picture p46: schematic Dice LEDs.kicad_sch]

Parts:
C1001, C1002, C1003, C1004, C1005, C1006, C1007, C1008, C1009: 100n; C_0603_1608Metric; JLCPCB Part # C113803
D1097, D1098, D1099, D1100, D1101, D1102, D1103, D1104, D1105: WS2812B; WS2812-mini; JLCPCB Part # C527089
R1004: 470R; R_0603_1608Metric

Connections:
/Dice LEDs/NP_3: R1004.1; also elsewhere on the board
GND: C1001.2, C1002.2, C1003.2, C1004.2, C1005.2, C1006.2, C1007.2, C1008.2, C1009.2, D1097.3 (VSS), D1098.3 (VSS), D1099.3 (VSS), D1100.3 (VSS), D1101.3 (VSS), D1102.3 (VSS), D1103.3 (VSS), D1104.3 (VSS), D1105.3 (VSS); also elsewhere on the board
unnamed: D1097.4 (DIN), R1004.2
unnamed: D1097.2 (DOUT), D1098.4 (DIN)
unnamed: D1098.2 (DOUT), D1099.4 (DIN)
unnamed: D1099.2 (DOUT), D1100.4 (DIN)
unnamed: D1100.2 (DOUT), D1101.4 (DIN)
unnamed: D1101.2 (DOUT), D1102.4 (DIN)
unnamed: D1102.2 (DOUT), D1103.4 (DIN)
unnamed: D1103.2 (DOUT), D1104.4 (DIN)
unnamed: D1104.2 (DOUT), D1105.4 (DIN)
VCC: C1001.1, C1002.1, C1003.1, C1004.1, C1005.1, C1006.1, C1007.1, C1008.1, C1009.1, D1097.1 (VDD), D1098.1 (VDD), D1099.1 (VDD), D1100.1 (VDD), D1101.1 (VDD), D1102.1 (VDD), D1103.1 (VDD), D1104.1 (VDD), D1105.1 (VDD); also elsewhere on the board

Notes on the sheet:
Dice LEDs

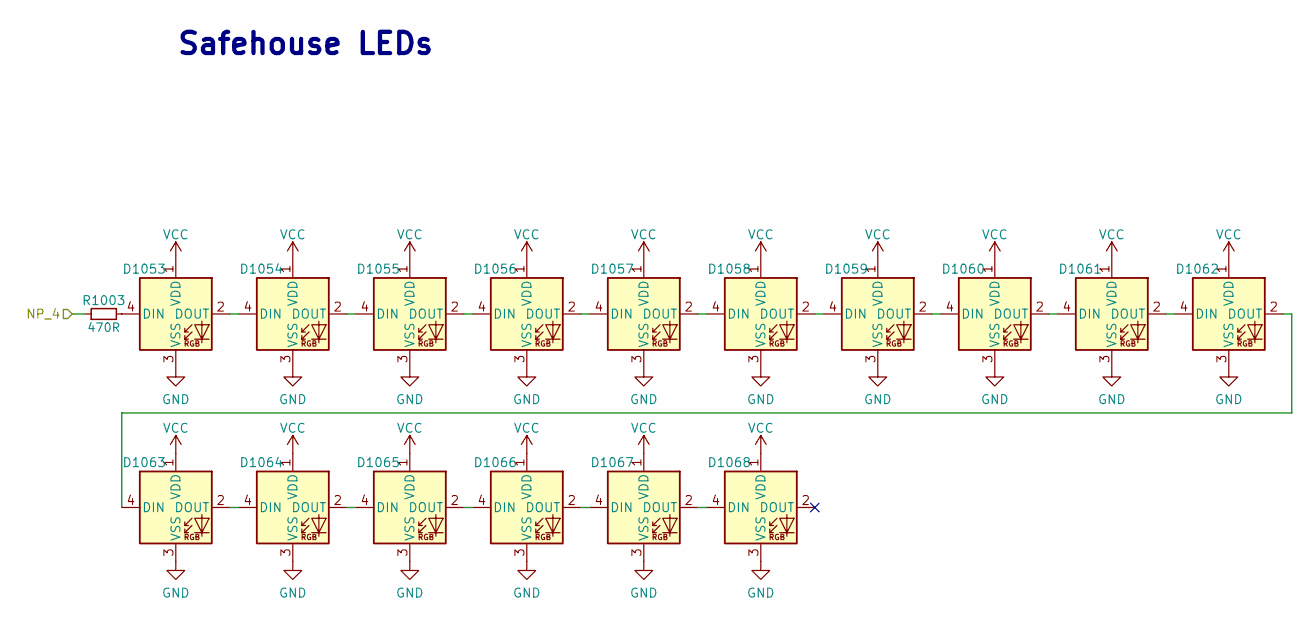
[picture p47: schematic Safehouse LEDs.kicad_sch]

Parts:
D1053, D1054, D1055, D1056, D1057, D1058, D1059, D1060, D1061, D1062, D1063, D1064, D1065, D1066, D1067, D1068: WS2812B; LED_WS2812B_edited
R1003: 470R; R_0603_1608Metric

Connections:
/Microcontroller/NP_4: R1003.1; also elsewhere on the board
GND: D1053.3 (VSS), D1054.3 (VSS), D1055.3 (VSS), D1056.3 (VSS), D1057.3 (VSS), D1058.3 (VSS), D1059.3 (VSS), D1060.3 (VSS), D1061.3 (VSS), D1062.3 (VSS), D1063.3 (VSS), D1064.3 (VSS), D1065.3 (VSS), D1066.3 (VSS), D1067.3 (VSS), D1068.3 (VSS); also elsewhere on the board
unnamed: D1053.4 (DIN), R1003.2
unnamed: D1053.2 (DOUT), D1054.4 (DIN)
unnamed: D1054.2 (DOUT), D1055.4 (DIN)
unnamed: D1055.2 (DOUT), D1056.4 (DIN)
unnamed: D1056.2 (DOUT), D1057.4 (DIN)
unnamed: D1057.2 (DOUT), D1058.4 (DIN)
unnamed: D1058.2 (DOUT), D1059.4 (DIN)
unnamed: D1059.2 (DOUT), D1060.4 (DIN)
unnamed: D1060.2 (DOUT), D1061.4 (DIN)
unnamed: D1061.2 (DOUT), D1062.4 (DIN)
unnamed: D1062.2 (DOUT), D1063.4 (DIN)
unnamed: D1063.2 (DOUT), D1064.4 (DIN)
unnamed: D1064.2 (DOUT), D1065.4 (DIN)
unnamed: D1065.2 (DOUT), D1066.4 (DIN)
unnamed: D1066.2 (DOUT), D1067.4 (DIN)
unnamed: D1067.2 (DOUT), D1068.4 (DIN)
VCC: D1053.1 (VDD), D1054.1 (VDD), D1055.1 (VDD), D1056.1 (VDD), D1057.1 (VDD), D1058.1 (VDD), D1059.1 (VDD), D1060.1 (VDD), D1061.1 (VDD), D1062.1 (VDD), D1063.1 (VDD), D1064.1 (VDD), D1065.1 (VDD), D1066.1 (VDD), D1067.1 (VDD), D1068.1 (VDD); also elsewhere on the board

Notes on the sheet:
Safehouse LEDs

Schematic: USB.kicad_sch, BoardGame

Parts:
C201, C202, C204: 100n; C_0603_1608Metric; JLCPCB Part # C113803
C203: 10u; CP_EIA-3528-21_Kemet-B; JLCPCB Part # C2798040
FB201: 100 @ 100MHz; R_0603_1608Metric; JLCPCB Part # C107332
J201: USB_C_Receptacle_USB2.0; USB_C_Receptacle_HRO_TYPE-C-31-M-12
R201, R204: 1k; R_0603_1608Metric
R202, R203: 5k1; R_0603_1608Metric; JLCPCB Part # C3017721
U201: USBLC6-2SC6; SOT-23-6; JLCPCB Part # C3029034
U202: CH340C; SOIC-16_3.9x9.9mm_P1.27mm

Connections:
/Microcontroller/RESET: C204.1; also elsewhere on the board
/Microcontroller/RX: R201.1; also elsewhere on the board
/Microcontroller/TX: R204.1; also elsewhere on the board
/USB/USB: FB201.1, J201.A4 (VBUS), J201.A9 (VBUS), J201.B4 (VBUS), J201.B9 (VBUS)
GND: C201.2, C202.2, C203.2, J201.A1 (GND), J201.A12 (GND), J201.B1 (GND), J201.B12 (GND), R202.2, R203.2, U201.2 (GND), U202.1 (GND); also elsewhere on the board
unnamed: J201.A5 (CC1), R203.1
unnamed: J201.B5 (CC2), R202.1
unnamed: R204.2, U202.3 (RXD)
unnamed: R201.2, U202.2 (TXD)
unnamed: C201.1, U202.4 (V3)
unnamed: C204.2, U202.13 (~DTR)
USB_CONN_D+: J201.A6 (D+), J201.B6 (D+), U201.3 (I/O2)
USB_CONN_D-: J201.A7 (D-), J201.B7 (D-), U201.1 (I/O1)
USB_D+: U201.4 (I/O2), U202.5 (UD+)
USB_D-: U201.6 (I/O1), U202.6 (UD-)
VBUS: C202.1, C203.1, FB201.2, U201.5 (VBUS), U202.16 (VCC); also elsewhere on the board

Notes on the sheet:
Shield is grounded at the host side (PC) so NC here.
CH340C USB-UART IC
ESD protection IC
The device must have 5.1k pull-down on the its port CC pin (on both pins). Once the C-C cable is connected between two link partners, the DFP (host) will sense the drag by 5.1k resistor (from device side). As result, it will turn the VBUS on. This is how a host recognizes that a connection has been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
SBU1/SBU2: these are low-speed lines used only for Alternate Mode and accessory mode. For example, with DisplayPort, AUX+/AUX– transmit over the SBU lines. For audio adapter accessory mode, these lines are used for the microphone input and analog GND.
Ferrite bead needs to be placed close to USB connector on PCB

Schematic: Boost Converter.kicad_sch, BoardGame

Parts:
C601, C602: 22u / 16V; C_1210_3225Metric; JLCPCB Part # C337451
D601: SS12; D_SMA; JLCPCB Part # C2985002
L601: 4R7; Inductor_4mm(5x5mm pads)
R601: 100k; R_0603_1608Metric
R602: 13k3; R_0603_1608Metric; JLCPCB Part # C185373
U601: MT3608; SOT-23-6; JLCPCB Part # C2932326

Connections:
+5V: C602.1, D601.1 (K), R601.1; also elsewhere on the board
/Boost Converter/FB: R601.2, R602.1, U601.3 (FB)
/Boost Converter/L_OUT: D601.2 (A), L601.2, U601.1 (SW)
GND: C601.2, C602.2, R602.2, U601.2 (GND); also elsewhere on the board
VCC: C601.1, L601.1, U601.4 (EN), U601.5 (IN); also elsewhere on the board

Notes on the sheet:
Input and output ceramic capacitors of 22μF are recommended. For better voltage filtering, ceramic capacitors with low ESR are recommended (X7R).
Schottky diode is a good choice for MT3608 because of its low forward voltage drop and fast reverses recovery.
The recommended values of inductor are 4.7 to 22μH. The inductor should have low core loss at 1.2MHz and low DCR for better efficiency.
The internal reference V_{REF} is 0.6V (Typical). V_{OUT} = V_{REF} * (1 + R_{1}/R_{2}) V_{OUT} = 0.6 * (1 + 100k/13.3k) = 5.11V

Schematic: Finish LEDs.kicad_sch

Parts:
D1069, D1070, D1071, D1072, D1073, D1074, D1075, D1076, D1077, D1078, D1079, D1080, D1081, D1082, D1083, D1084: WS2812B; LED_WS2812B_edited
R1001: 470R; R_0603_1608Metric

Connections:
/Finish LEDs/NP_1: R1001.1; also elsewhere on the board
GND: D1069.3 (VSS), D1070.3 (VSS), D1071.3 (VSS), D1072.3 (VSS), D1073.3 (VSS), D1074.3 (VSS), D1075.3 (VSS), D1076.3 (VSS), D1077.3 (VSS), D1078.3 (VSS), D1079.3 (VSS), D1080.3 (VSS), D1081.3 (VSS), D1082.3 (VSS), D1083.3 (VSS), D1084.3 (VSS); also elsewhere on the board
unnamed: D1069.4 (DIN), R1001.2
unnamed: D1069.2 (DOUT), D1070.4 (DIN)
unnamed: D1070.2 (DOUT), D1071.4 (DIN)
unnamed: D1071.2 (DOUT), D1072.4 (DIN)
unnamed: D1072.2 (DOUT), D1073.4 (DIN)
unnamed: D1073.2 (DOUT), D1074.4 (DIN)
unnamed: D1074.2 (DOUT), D1075.4 (DIN)
unnamed: D1075.2 (DOUT), D1076.4 (DIN)
unnamed: D1076.2 (DOUT), D1077.4 (DIN)
unnamed: D1077.2 (DOUT), D1078.4 (DIN)
unnamed: D1078.2 (DOUT), D1079.4 (DIN)
unnamed: D1079.2 (DOUT), D1080.4 (DIN)
unnamed: D1080.2 (DOUT), D1081.4 (DIN)
unnamed: D1081.2 (DOUT), D1082.4 (DIN)
unnamed: D1082.2 (DOUT), D1083.4 (DIN)
unnamed: D1083.2 (DOUT), D1084.4 (DIN)
VCC: D1069.1 (VDD), D1070.1 (VDD), D1071.1 (VDD), D1072.1 (VDD), D1073.1 (VDD), D1074.1 (VDD), D1075.1 (VDD), D1076.1 (VDD), D1077.1 (VDD), D1078.1 (VDD), D1079.1 (VDD), D1080.1 (VDD), D1081.1 (VDD), D1082.1 (VDD), D1083.1 (VDD), D1084.1 (VDD); also elsewhere on the board

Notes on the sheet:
Finish LEDs

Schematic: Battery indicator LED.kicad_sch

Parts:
D1106: WS2812B; WS2812-mini
R1006: 470R; R_0603_1608Metric

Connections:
/Battery indicator LED/NP_6: R1006.1; also elsewhere on the board
GND: D1106.3 (VSS); also elsewhere on the board
unnamed: D1106.4 (DIN), R1006.2
VCC: D1106.1 (VDD); also elsewhere on the board

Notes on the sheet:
Battery LED

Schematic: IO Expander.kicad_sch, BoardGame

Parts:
C401: 100n; C_0603_1608Metric; JLCPCB Part # C113803
J401, J402, J403, J404: Conn_02x03_Odd_Even; 2x03_P1.27mm_conn
J405, J406, J407, J408: Conn_01x02_Female; PinHeader_1x02_P1.27mm_Vertical
R401, R402: 4k7; R_0603_1608Metric; JLCPCB Part # C114662
U401: PCF8575; SOIC-24W_7.5x15.4mm_P1.27mm

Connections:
+5V: C401.1, J401.3, J401.4, J402.3, J402.4, J403.3, J403.4, J404.3, J404.4, J405.1, J405.2, R401.1, R402.1, U401.24 (VCC); also elsewhere on the board
/IO Expander/INT: U401.1 (~INT); also elsewhere on the board
/IO Expander/SCL: R401.2, U401.22 (SCL); also elsewhere on the board
/IO Expander/SDA: R402.2, U401.23 (SDA); also elsewhere on the board
GND: C401.2, J401.1, J402.1, J403.1, J404.1, J406.1, J406.2, U401.12 (GND); also elsewhere on the board
TP_1: J401.2, U401.4 (P00)
TP_2: J401.6, U401.5 (P01)
TP_3: J401.5, U401.6 (P02)
TP_4: J402.2, U401.7 (P03)
TP_5: J402.6, U401.8 (P04)
TP_6: J402.5, U401.9 (P05)
TP_7: J403.2, U401.10 (P06)
TP_8: J403.6, U401.11 (P07)
TP_9: J403.5, U401.13 (P10)
TP_10: J404.2, U401.14 (P11)
TP_11: J404.6, U401.15 (P12)
TP_12: J404.5, U401.16 (P13)
TP_13: J408.1, J408.2, U401.17 (P14)

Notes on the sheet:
Dice touchpad connectors
Touchpad connectors
PCF8575 I/O Expander

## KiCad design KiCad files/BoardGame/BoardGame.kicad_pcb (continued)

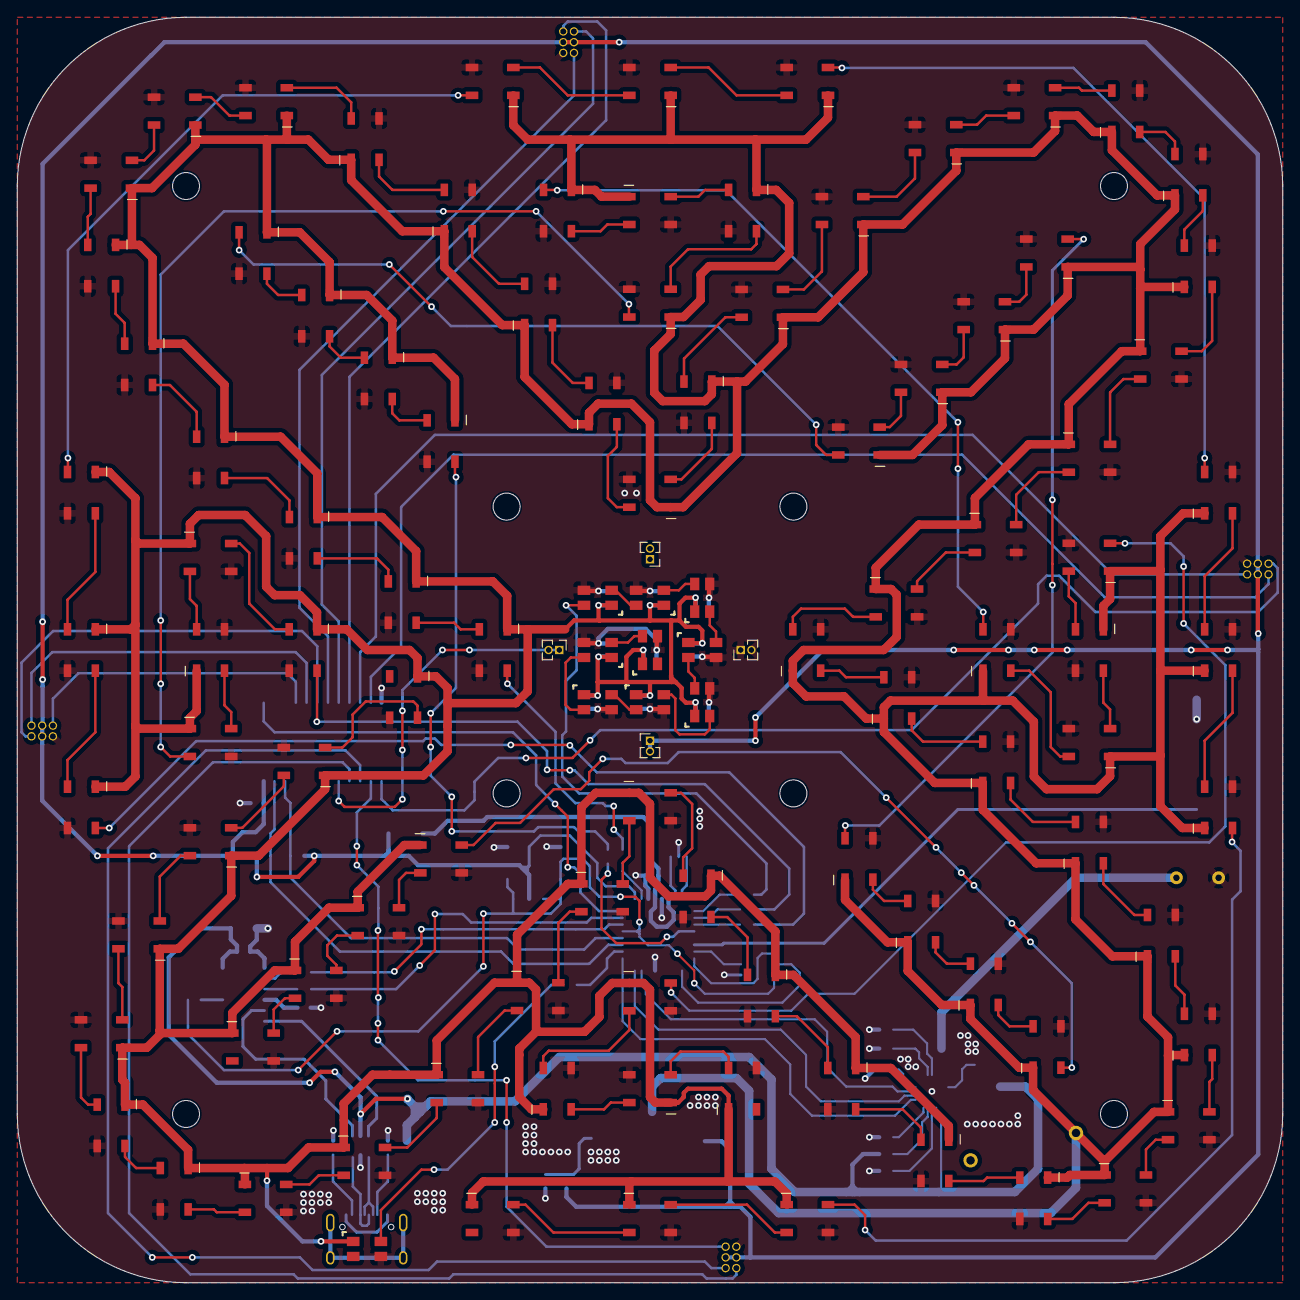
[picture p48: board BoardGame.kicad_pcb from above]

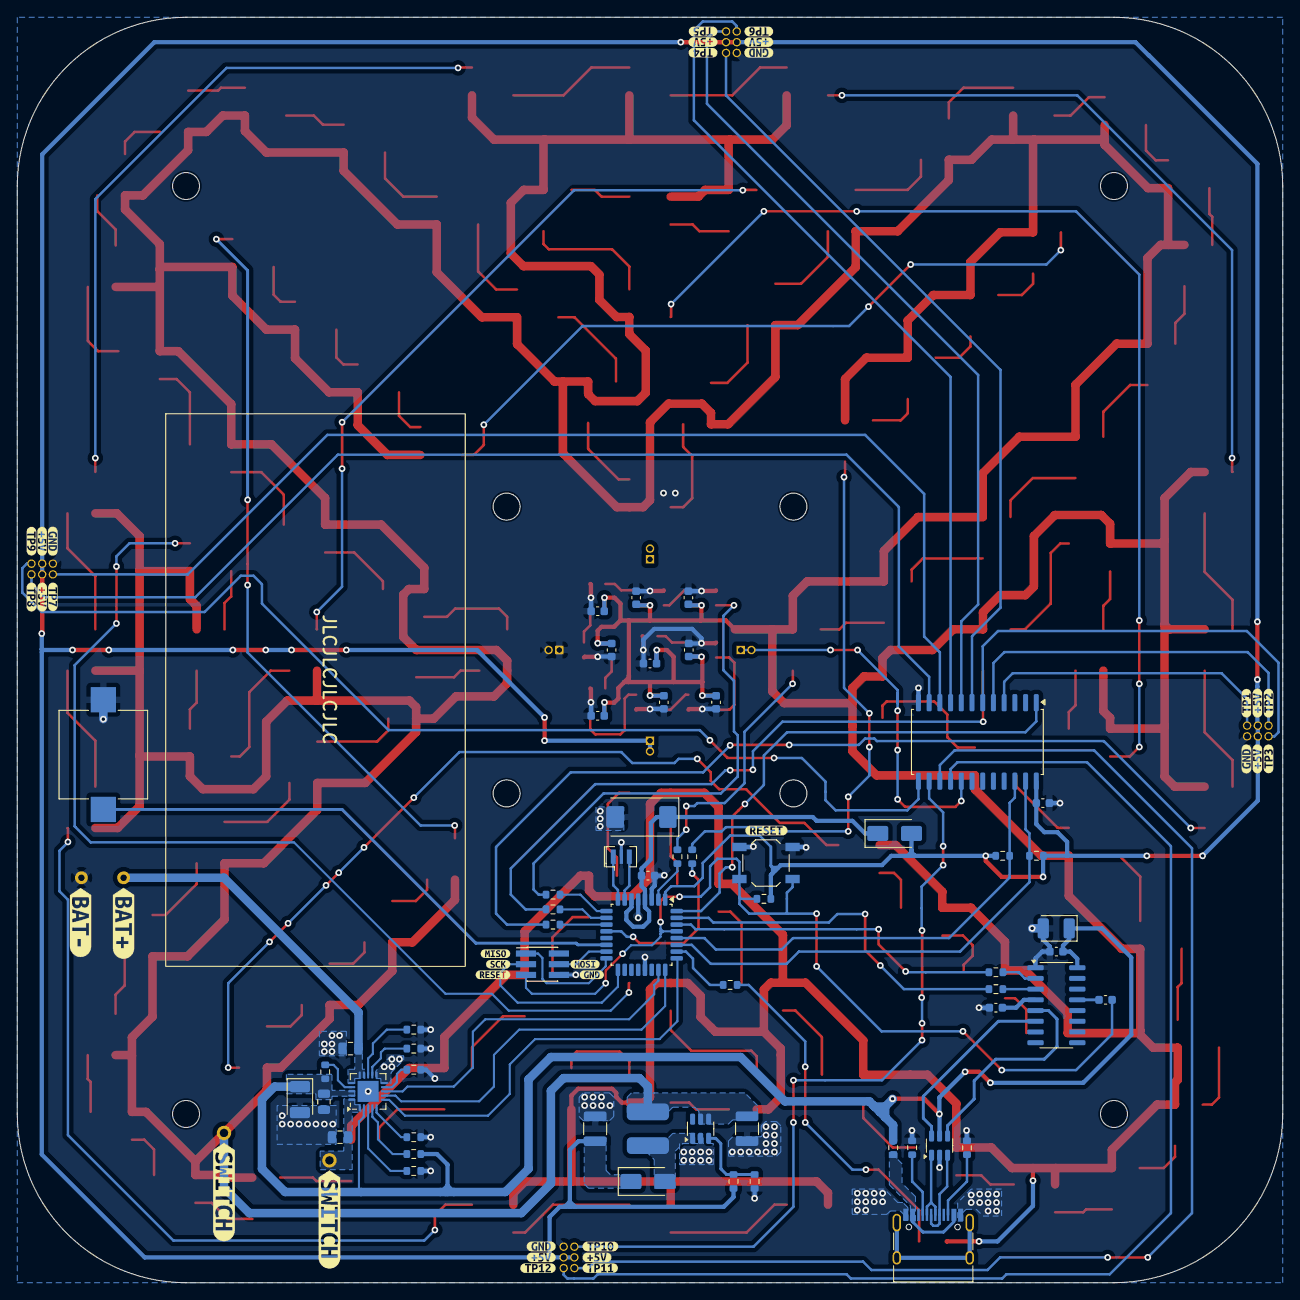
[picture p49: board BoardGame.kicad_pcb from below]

Board: 2 copper layers, 150.0 x 150.0 mm, 218 parts (94 on the bottom side), 167 nets.

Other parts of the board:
kibuzzard-635B9A1E, kibuzzard-635B9A1E#2: G***; kibuzzard-635B9A1E
kibuzzard-635BA7B4: G***; kibuzzard-635BA7B4
kibuzzard-635BA762: G***; kibuzzard-635BA762
kibuzzard-635CF4BC: G***; kibuzzard-635CF4BC
kibuzzard-635CF4CF: G***; kibuzzard-635CF4CF
kibuzzard-635CF4E4: G***; kibuzzard-635CF4E4
kibuzzard-635CF6FA, kibuzzard-635CF6FA#2, kibuzzard-635CF6FA#3, kibuzzard-635CF6FA#4: G***; kibuzzard-635CF6FA
kibuzzard-635CF7DB: G***; kibuzzard-635CF7DB
kibuzzard-635CF483: G***; kibuzzard-635CF483
kibuzzard-635CF507: G***; kibuzzard-635CF507
kibuzzard-635CF752, kibuzzard-635CF752#2, kibuzzard-635CF752#3, kibuzzard-635CF752#4, kibuzzard-635CF752#5, kibuzzard-635CF752#6, kibuzzard-635CF752#7, kibuzzard-635CF752#8: G***; kibuzzard-635CF752
kibuzzard-635CF795: G***; kibuzzard-635CF795
kibuzzard-635CF884: G***; kibuzzard-635CF884
kibuzzard-635CFA5F: G***; kibuzzard-635CFA5F
kibuzzard-635CFA8A: G***; kibuzzard-635CFA8A
kibuzzard-635CFAA6: G***; kibuzzard-635CFAA6
kibuzzard-635CFAF1: G***; kibuzzard-635CFAF1
kibuzzard-635CFB05: G***; kibuzzard-635CFB05
kibuzzard-635CFB13: G***; kibuzzard-635CFB13
kibuzzard-635CFD4A: G***; kibuzzard-635CFD4A
kibuzzard-635CFDAF: G***; kibuzzard-635CFDAF
kibuzzard-635CFDBF: G***; kibuzzard-635CFDBF
kibuzzard-636375F6: G***; kibuzzard-636375F6

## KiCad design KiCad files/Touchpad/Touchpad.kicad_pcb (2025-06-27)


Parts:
C1, C3, C5: 0-50 pF; C_0603_1608Metric
C2, C4, C6: 100n; C_0603_1608Metric
J1: Conn_02x03_Counter_Clockwise; PinHeader_2x03_P1.27mm_Vertical_SMD
TP1: TestPoint; TP_11mm_kvacica
TP2: TestPoint; TP_11mm_strelicaLijevo
TP3: TestPoint; TP_11mm_strelicaDesno
U1, U2, U3: TTP223-BA6; SOT-23-6

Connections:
+5V: C2.1, C4.1, C6.1, J1.3, J1.4, U1.5 (VDD), U2.5 (VDD), U3.5 (VDD)
GND: C1.2, C2.2, C3.2, C4.2, C5.2, C6.2, J1.6, U1.2 (VSS), U2.2 (VSS), U3.2 (VSS)
unnamed: C1.1, TP1.1, U1.3 (I)
unnamed: C3.1, TP2.1, U2.3 (I)
unnamed: C5.1, TP3.1, U3.3 (I)
TP1: J1.5, U1.1 (Q)
TP2: J1.1, U2.1 (Q)
TP3: J1.2, U3.1 (Q)

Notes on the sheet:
TOUCHPAD ICs
CONNECTOR



Board: 2 copper layers, 56.0 x 16.0 mm, 13 parts (10 on the bottom side), 8 nets.

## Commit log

2022-02-09 More PCBS
    [BoostConverter.kicad_sch, BoostConverter.sch, CNLJS.kicad_sch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]
2022-04-19 FieldBoard created
    [FieldBoard.kicad_pcb, FieldBoard.kicad_sch]
2022-04-26 layout v1
    [Cube.kicad_sch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]
2022-06-29 update v2
    [CNLJS.kicad_pcb]
2022-07-03 buzzer footprint
2022-07-03 shematic update
    [BoostConverter.kicad_sch, CNLJS.kicad_pcb, CNLJS.kicad_sch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]
2022-11-08 to-do added
    [BoardGame.kicad_sch, IO Expander.kicad_sch]
2022-11-14 Remove old files
    [BOM-Touchpad.csv, BoostConverter.kicad_sch, BoostConverter.sch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]
2022-11-15 Update BoardGame-front and back.PNG
2022-11-15 Create BoardGame-front and back.png
2022-11-23 Schematic update
    [Battery charger.kicad_sch, Battery indicator LED.kicad_sch, BoardGame.kicad_pcb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]
2023-01-13 Update BoardGame BOM.xlsx
    [BoardGame BOM.xlsx]
2024-05-06 Create BoardGame-Battery charger.pdf
